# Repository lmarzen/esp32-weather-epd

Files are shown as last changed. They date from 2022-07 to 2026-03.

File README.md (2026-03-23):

# ESP32 E-Paper Weather Display

A low-power weather display using a wifi-enabled ESP32 microcontroller and a 7.5" E-Paper display. Weather data is fetched from the OpenWeatherMap API, and an onboard sensor provides indoor temperature and humidity.

<p float="left">
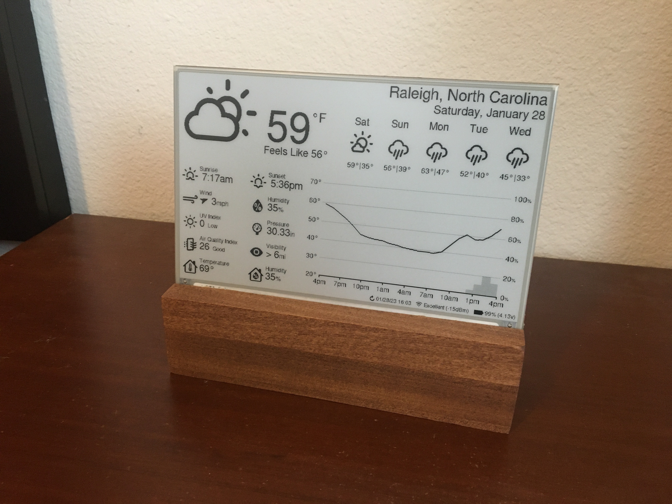
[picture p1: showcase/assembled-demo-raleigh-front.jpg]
  
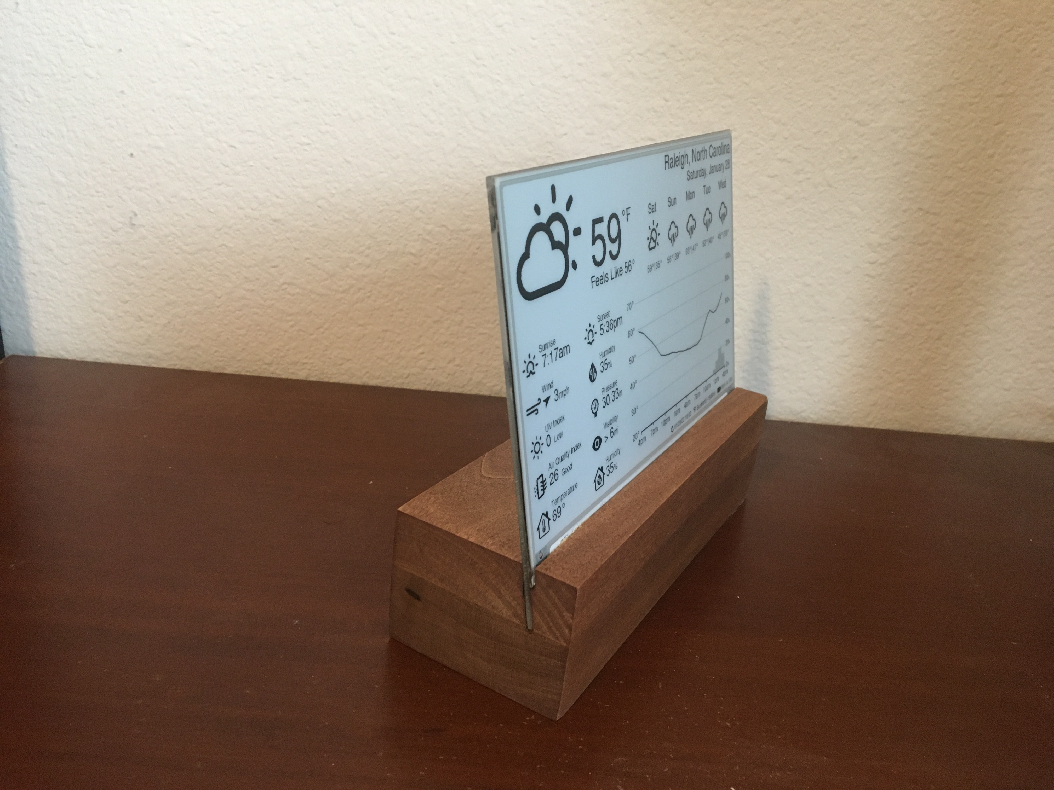
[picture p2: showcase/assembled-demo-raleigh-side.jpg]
  
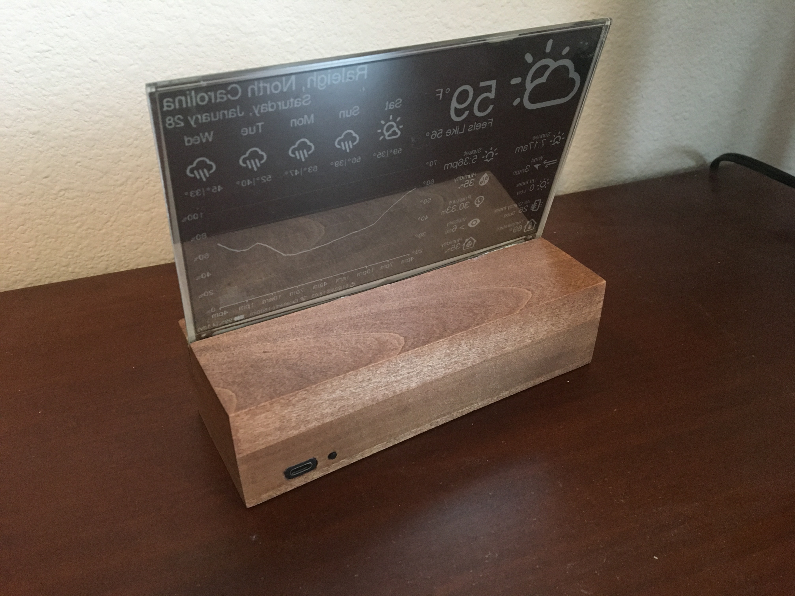
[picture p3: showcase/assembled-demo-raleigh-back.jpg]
  
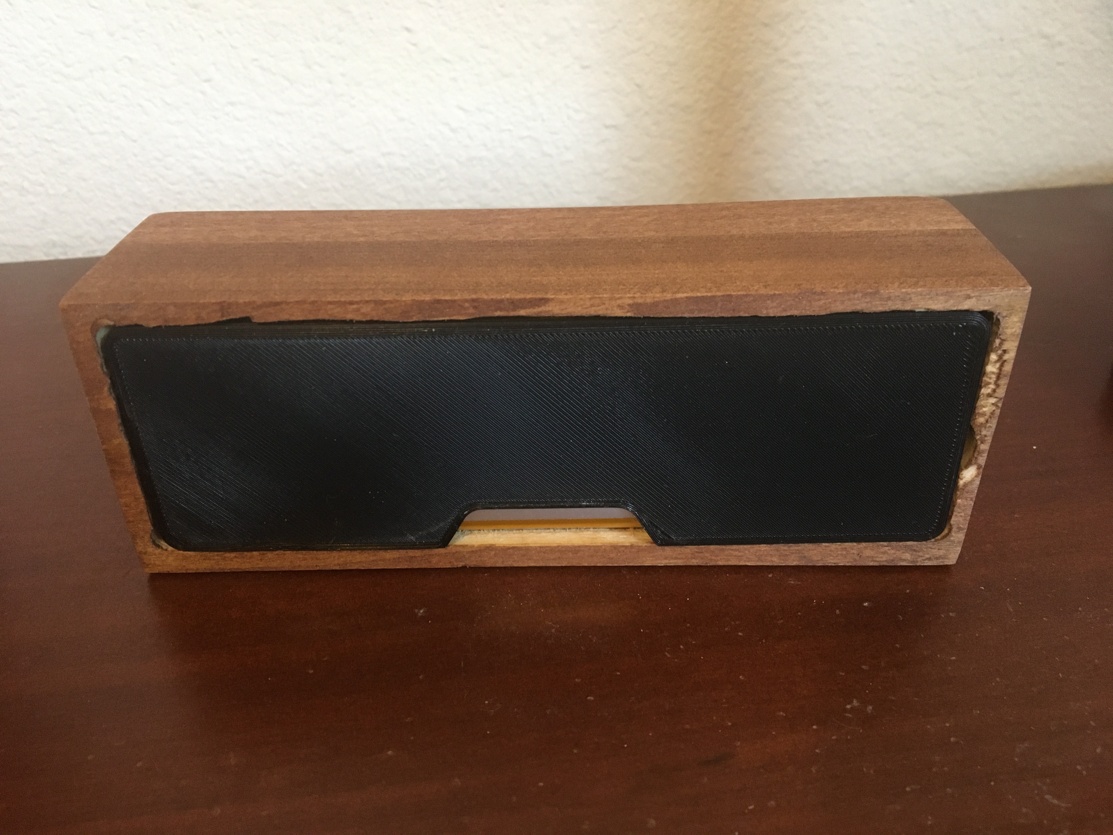
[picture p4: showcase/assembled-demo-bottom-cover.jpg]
  
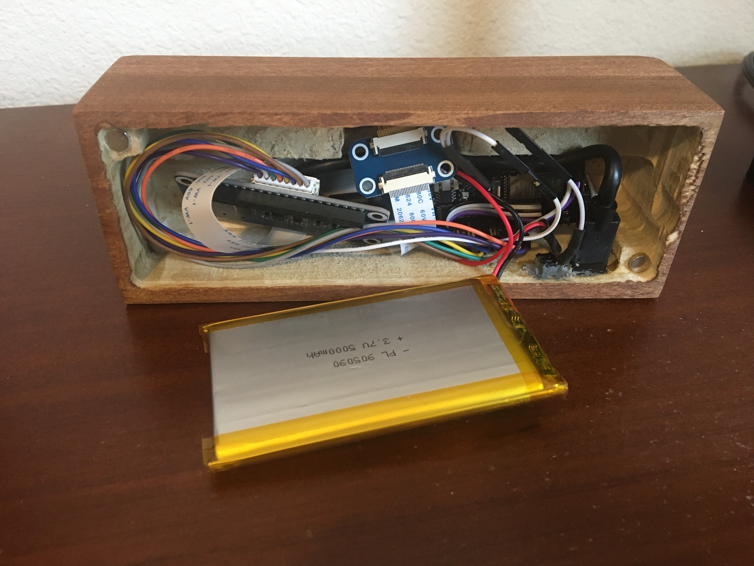
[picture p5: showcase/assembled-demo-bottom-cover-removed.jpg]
  
</p>

## Features

- Ultra-low power consumption: ~14μA in sleep, ~83mA during refresh (~15s).

- Long battery life: 6-12 months on a 5000mAh battery with 30-minute update frequency.

- Customizable display: Supports multiple languages, units, time/date formats, AQI scales, personalization options, and much more.

- Easy recharging: USB-C charging with battery monitoring.

The hourly outlook graph (bottom right) shows a line indicating temperature and shaded bars indicating probability of precipitation (or optionally volume of precipitation).

Here are two (slightly outdated) examples utilizing various configuration options:

<p float="left">
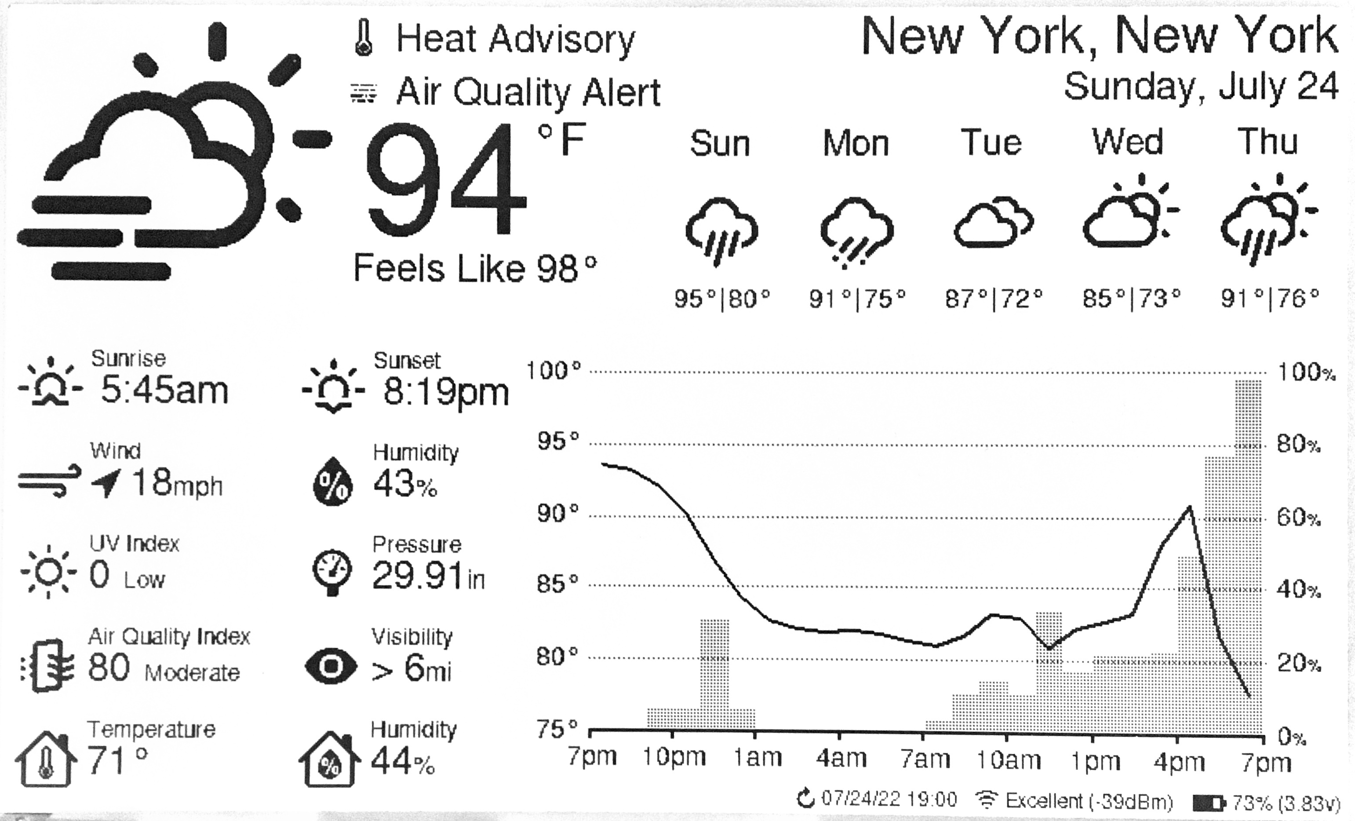
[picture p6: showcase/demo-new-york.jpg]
  
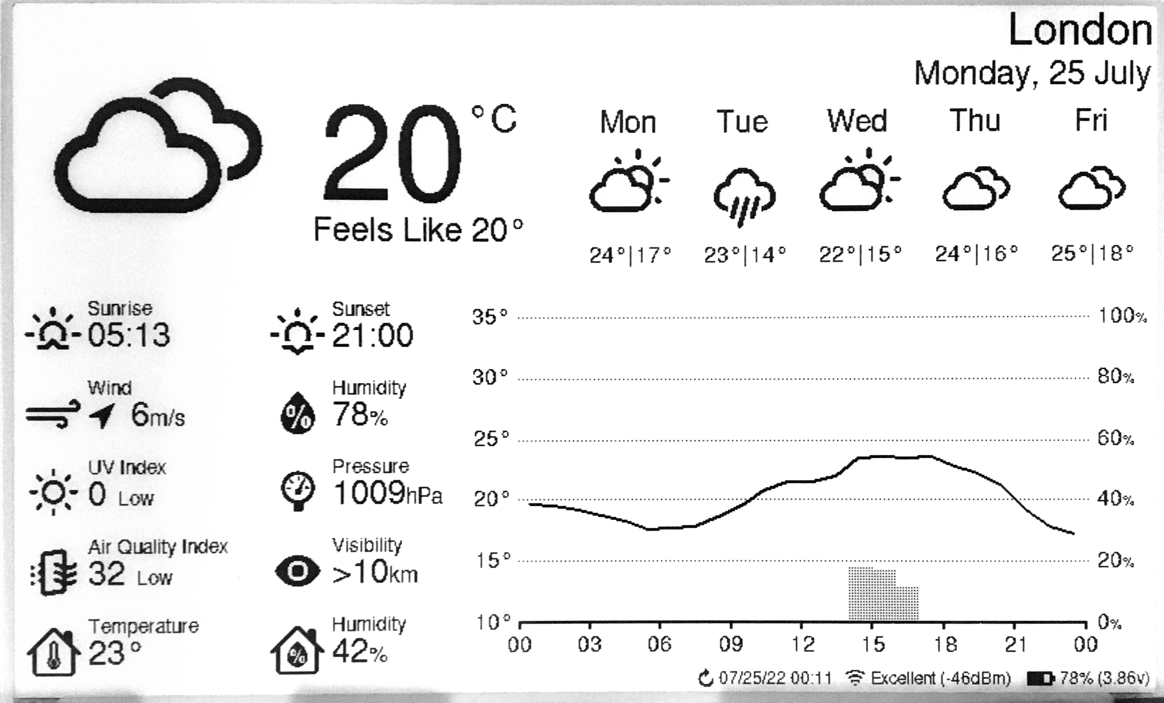
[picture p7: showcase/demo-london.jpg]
  
</p>

## Contents

- [Required Components](#required-components)
  - [Panel Support](#panel-support)
  - [Enclosure Options](#enclosure-options)
  - [Solder-Free Component Selection](#solder-free-component-selection-optional)
- [Setup Guide](#setup-guide)
  - [Wiring](#wiring)
  - [Configuration, Compilation, and Upload](#configuration-compilation-and-upload)
  - [OpenWeatherMap API Key](#openweathermap-api-key)
- [Error Messages and Troubleshooting](#error-messages-and-troubleshooting)
  - [Low Battery](#low-battery)
  - [WiFi Connection](#wifi-connection)
  - [API Error](#api-error)
  - [Time Server Error](#time-server-error)
- [Licensing](#licensing)

## Required Components

  Some links below are affiliate links. Using them helps support the project at no extra cost to you—thanks for your support!

  | Component Type  | Component                                    | Notes                                                     | Link                                                                         |
  |-----------------|----------------------------------------------|-----------------------------------------------------------|------------------------------------------------------------------------------|
  | ESP32           | FireBeetle 2 ESP32-E                         | Features low-power design, USB-C, and battery management. | Available [here](https://www.dfrobot.com/product-2195.html?tracking=PfSxQ8). |
  | E-Paper Display | See [Panel Support](#panel-support).         | See [Panel Support](#panel-support).                      | See [Panel Support](#panel-support).                                         |
  | Adapter Board   | DESPI-C02                                    | Waveshare HATs (rev 2.2/2.3) are not recommended.         | Available [here](https://www.aliexpress.us/item/3256804446769469.html).      |
  | Sensor          | BME280                                       | Temperature, humidity, and pressure. 3.3V/5V compatible.  | Available from multiple vendors.                                             |
  | Battery         | 3.7V LiPo w/ JST-PH2.0 connector             | Any capacity (e.g., 5000mAh for 6+ months runtime)        | Available from multiple vendors.                                             |
  | Enclosure       | See [Enclosure Options](#enclosure-options). | See [Enclosure Options](#enclosure-options).              | See [Enclosure Options](#enclosure-options).                                 |

Other items needed:
- Wires ("Jumper Wires" if looking to minimize/avoid soldering).
- Solder Iron + Solder (unless following [Solder-Free Component Selection](#solder-free-component-selection-optional)).
- Linux, Windows, or MacOS computer (used to configure and install ESP32 firmware).
- Push Button (optional, if you want a reset button mounted on your enslosure, else you can use the on-board reset button).

### Panel Support

  Waveshare and Good Display make equivalent panels. Either variant will work.

  | Panel                                   | Resolution | Colors          | Notes                                                                                                                 |
  |-----------------------------------------|------------|-----------------|-----------------------------------------------------------------------------------------------------------------------|
  | Waveshare 7.5in e-paper (v2)            | 800x480px  | Black/White     | Available [here](https://www.waveshare.com/product/7.5inch-e-paper.htm). (recommended)                                |
  | Good Display 7.5in e-paper (GDEY075T7)  | 800x480px  | Black/White     | Available [here](https://www.aliexpress.com/item/3256802683908868.html).             |
  | Waveshare 7.5in e-Paper (B)             | 800x480px  | Red/Black/White | Available [here](https://www.waveshare.com/product/7.5inch-e-paper-b.htm).                                            |
  | Good Display 7.5in e-paper (GDEY075Z08) | 800x480px  | Red/Black/White | Available [here](https://www.aliexpress.com/item/3256803540460035.html).                                              |
  | Waveshare 7.3in ACeP e-Paper (F)        | 800x480px  | 7-Color         | Available [here](https://www.waveshare.com/product/displays/e-paper/epaper-1/7.3inch-e-paper-f.htm).                  |
  | Good Display 7.3in e-paper (GDEY073D46) | 800x480px  | 7-Color         | Available [here](https://www.aliexpress.com/item/3256805485098421.html).                                              |
  | Waveshare 7.5in e-paper (v1)            | 640x384px  | Black/White     | Limited support. Some information not displayed, see [image](showcase/demo-waveshare75-version1.jpg).                 |
  | Good Display 7.5in e-paper (GDEW075T8)  | 640x384px  | Black/White     | Limited support. Some information not displayed, see [image](showcase/demo-waveshare75-version1.jpg).                 |

  This software has limited support for accent colors. E-paper panels with additional colors tend to have longer refresh times, which will reduce battery life.

### Enclosure Options

You'll want a nice way to show off your project. Here are a few popular choices.

- DIY Wooden
  - I made a small stand by hollowing out a piece of wood from the bottom. On the back, I used a short USB extension cable so that I can charge the battery without needing to remove the components from the stand. I also wired a small reset button to refresh the display manually. Additionally, I 3d printed a cover for the bottom, which is held on by magnets. The E-paper screen is very thin, so I used a thin piece of acrylic to support it.
  - Measurements:
    - depth = 63mm <br>
      height = 49mm <br>
      width = 170.2mm (= width of the screen) <br>
      screen angle = 80deg <br>
      screen is 15mm from the front
- 3D Printable
  - Here is a list of community designs.
  
    | Contributor                                                          | Link                                                                                                      |
    |----------------------------------------------------------------------|-----------------------------------------------------------------------------------------------------------|
    | [Kingfisher](https://www.printables.com/@Kingfisher_32821)           | [Printables](https://www.printables.com/model/1139047-weather-station-e-ink-frame)                        |
    | [Francois Allard](https://www.printables.com/@FrAllard_1585397)      | [Printables](https://www.printables.com/model/791477-weather-station-using-a-esp32)                       |
    | [3D Nate](https://www.printables.com/@3DNate_451157)                 | [Printables](https://www.printables.com/model/661183-e-ink-weather-station-frame)                         |
    | [Sven F.](https://github.com/Spanholz)                               | [Printables](https://www.printables.com/model/657756-case-for-esp32-weather-station)                      |
    | [Layers Studio](https://www.printables.com/@LayersStudio)            | [Printables](https://www.printables.com/model/655768-esp32-e-paper-weather-display-stand)                 |
    | [PJ Veltri](https://www.printables.com/@PJVeltri_1590999)            | [Printables](https://www.printables.com/model/692944-base-and-display-holder-for-esp-32-e-paper-weather)  |
    | [TheMeanCanEHdian](https://www.printables.com/@TheMeanCanEH_1207348) | [Printables](https://www.printables.com/model/841458-weather-display-enclosure)                           |
    | [MPHarms](https://www.thingiverse.com/mpharms/designs)               | [Thingiverse](https://www.thingiverse.com/thing:6666148)                                                  |
    | [Plaste-Metz](https://www.printables.com/@PlasteMetz_576567)         | [Printables](https://www.printables.com/model/1160924-weather-station-case)                               |
    | [kenwch92](https://github.com/kenwch92)                              | [Printables](https://www.printables.com/model/1505838-over-engineered-display-stand-for-esp32-e-paper-we) |
    | [Eckerput](https://github.com/Eckerput)                              | [Thingiverse](https://www.thingiverse.com/thing:7112836)                                                  |
    | [Thomax ](https://www.printables.com/@Thomax_386720)                 | [Printables](https://www.printables.com/model/1363448-esp32-e-paper-weather-display) |

  - If you want to share your own 3D printable designs, your contributions are highly encouraged and welcome!
- Picture Frame

### Solder-Free Component Selection (Optional)

This project can be completed without any soldering, if you choose your component selection carefully.
- Buy "Jumper Wires" to connect your components.
- Buy the [FireBeetle 2 ESP32-E w/ Headers](https://www.dfrobot.com/product-2231.html?tracking=PfSxQ8).
- Buy a BME280 with headers soldered from the factory.
- Buy a reset switch that is compatible with jumper wires.

## Setup Guide

### Wiring

The battery can be charged by plugging the FireBeetle ESP32 into the wall via the USB-C connector while the battery is plugged into the ESP32's JST connector.

  > **Warning**
  > The polarity of JST-PH2.0 connectors is not standardized! You may need to swap the order of the wires in the connector.

NOTE: Waveshare now ships revision 2.3 of their e-paper HAT (no longer rev 2.2 ). Rev 2.3 has an additional `PWR` pin (not depicted in the wiring diagrams below); connect this pin to 3.3V.

IMPORTANT: The DESPI-C02 adapter has one physical switch that MUST be set correctly for the display to work.

- RESE: Set switch to position 0.47.

IMPORTANT: The Waveshare E-Paper Driver HAT has two physical switches that MUST be set correctly for the display to work.

- Display Config: Set switch to position B.

- Interface Config: Set switch to position 0.

Cut the low power pad for even longer battery life.

- From <https://wiki.dfrobot.com/FireBeetle_Board_ESP32_E_SKU_DFR0654>

  > Low Power Pad: This pad is specially designed for low power consumption. It is connected by default. You can cut off the thin wire in the middle with a knife to disconnect it. After disconnection, the static power consumption can be reduced by 500 μA. The power consumption can be reduced to 13 μA after controlling the maincontroller enter the sleep mode through the program. Note: when the pad is disconnected, you can only drive RGB LED light via the USB Power supply.

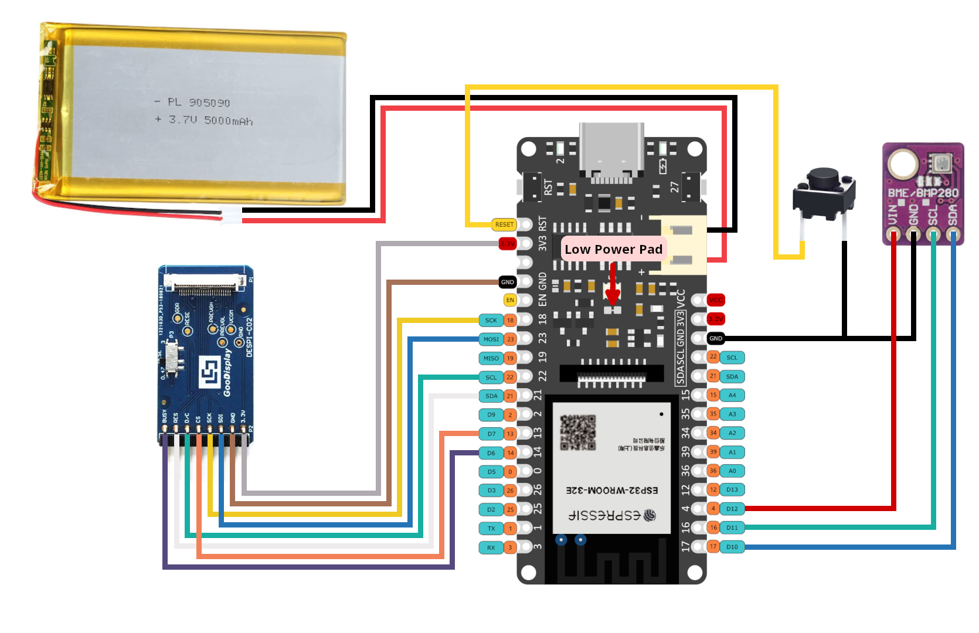
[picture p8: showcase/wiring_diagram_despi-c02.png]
Wiring diagram with DESPI-C02 driver board.


### Configuration, Compilation, and Upload

PlatformIO for VSCode is used for managing dependencies, code compilation, and uploading to ESP32.

1. Clone this repository or download and extract the .zip.

2. Install VSCode.

3. Follow these instructions to install the PlatformIO extension for VSCode: <https://platformio.org/install/ide?install=vscode>

4. Open the project in VSCode.

   a. File > Open Folder...

   b. Navigate to this project and select the folder called "platformio".

5. Configure Options.

   - Most configuration options are located in [config.cpp](platformio/src/config.cpp), with a few  in [config.h](platformio/include/config.h).

   - Important settings to configure in config.cpp:

     - WiFi credentials (ssid, password).

     - Open Weather Map API key (it's free, see next section for important notes about obtaining an API key).

     - Latitude and longitude.

     - Time and date formats.

     - Sleep duration.

   - Important settings to configure in config.h:

     - Units (Metric or Imperial).

   - Comments explain each option in detail.

6. Build and Upload Code.

   a. Connect ESP32 to your computer via USB.

   b. Click the upload arrow along the bottom of the VSCode window. (Should say "PlatformIO: Upload" if you hover over it.)

      - PlatformIO will automatically download the required third-party libraries, compile, and upload the code. :)

      - You will only see this if you have the PlatformIO extension installed.

      - If using a FireBeetle 2 ESP32-E and you receive the error `Wrong boot mode detected (0x13)! The chip needs to be in download mode.` unplug the power from the board, connect GPIO0 ([labeled 0/D5](https://wiki.dfrobot.com/FireBeetle_Board_ESP32_E_SKU_DFR0654#target_5)) to GND, and power it back up to put the board in download mode.

      - If you are getting other errors during the upload process, you may need to install drivers to allow you to upload code to the ESP32.

### OpenWeatherMap API Key

Sign up here to get an API key; it's free. <https://openweathermap.org/api>

This project will make calls to 2 different APIs ("One Call" and "Air Pollution").

- The One Call API 3.0 is only included in the "One Call by Call" subscription. This separate subscription includes 1,000 calls/day for free and allows you to pay only for the number of API calls made to this product.

Here's how to subscribe and avoid any credit card changes:
   - Go to <https://home.openweathermap.org/subscriptions/billing_info/onecall_30/base?key=base&service=onecall_30>
   - Follow the instructions to complete the subscription.
   - Go to <https://home.openweathermap.org/subscriptions> and set the "Calls per day (no more than)" to 1,000. This ensures you will never overrun the free calls.

## Error Messages and Troubleshooting

### Low Battery
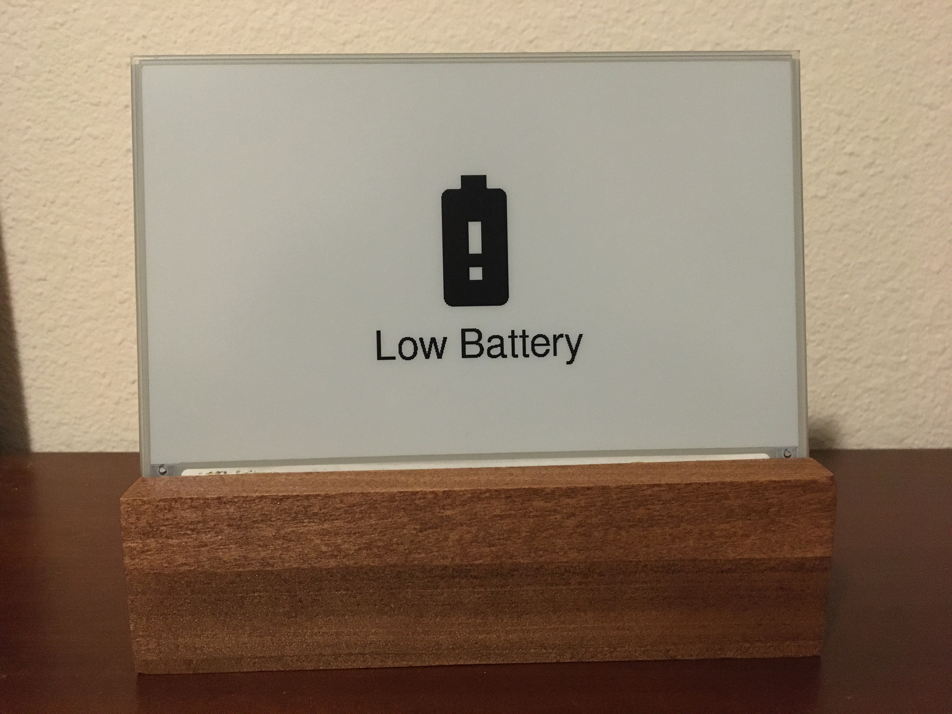
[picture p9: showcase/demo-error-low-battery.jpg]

This error screen appears once the battery voltage has fallen below LOW_BATTERY_VOLTAGE (default = 3.20v). The display will not refresh again until it detects battery voltage above LOW_BATTERY_VOLTAGE. When battery voltage is between LOW_BATTERY_VOLTAGE and VERY_LOW_BATTERY_VOLTAGE (default = 3.10v) the esp32 will deep-sleep for periods of LOW_BATTERY_SLEEP_INTERVAL (default = 30min) before checking battery voltage again. If the battery voltage falls between LOW_BATTERY_SLEEP_INTERVAL and CRIT_LOW_BATTERY_VOLTAGE (default = 3.00v), then the display will deep-sleep for periods VERY_LOW_BATTERY_SLEEP_INTERVAL (default = 120min). If battery voltage falls below CRIT_LOW_BATTERY_VOLTAGE, then the esp32 will enter hibernate mode and will require a manual push of the reset (RST) button to begin updating again.

<br clear="left"/>

### WiFi Connection
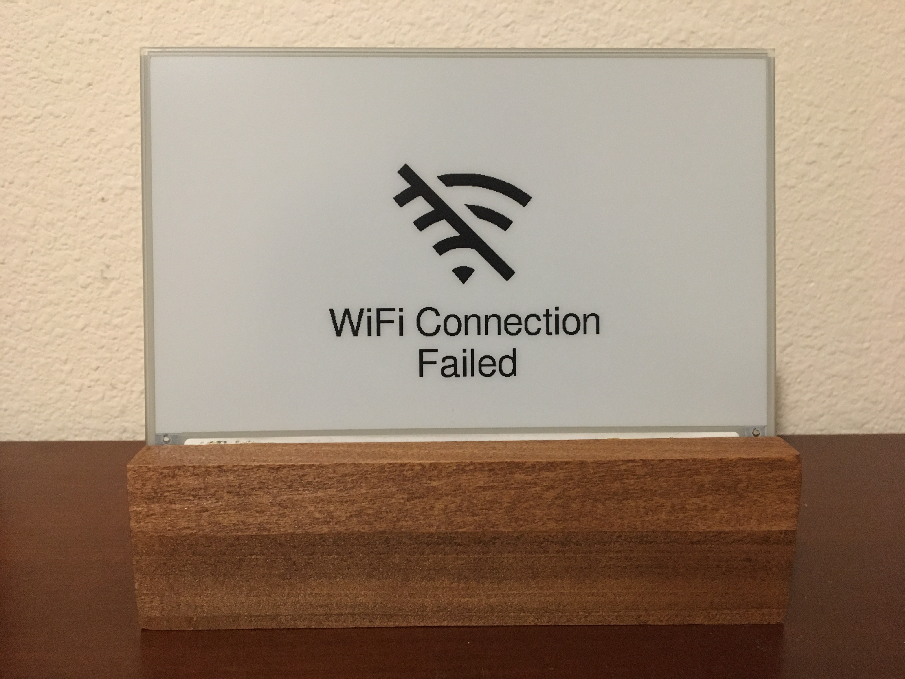
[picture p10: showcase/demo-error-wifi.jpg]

This error screen appears when the ESP32 fails to connect to WiFi. If the message reads "WiFi Connection Failed" this might indicate an incorrect password. If the message reads "SSID Not Available" this might indicate that you mistyped the SSID or that the esp32 is out of the range of the access point. The esp32 will retry once every SLEEP_DURATION (default = 30min).

<br clear="left"/>

### API Error
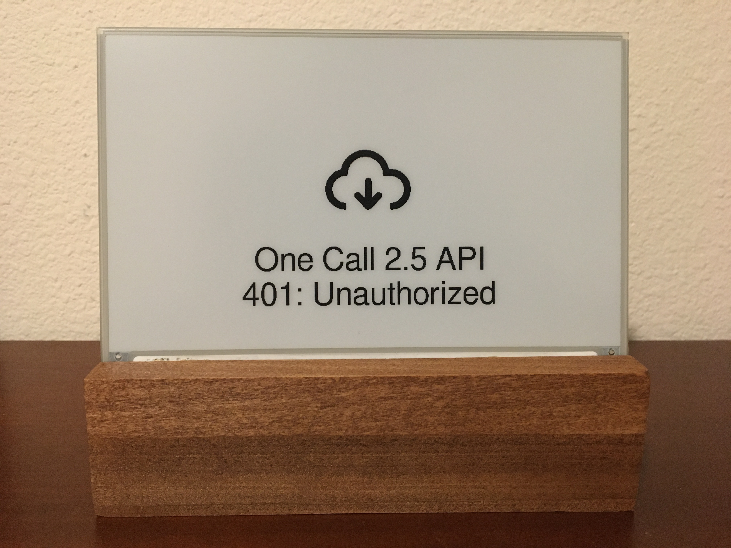
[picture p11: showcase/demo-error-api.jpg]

This error screen appears if an error (client or server) occurs when making an API request to OpenWeatherMap. The second line will give the error code followed by a descriptor phrase. Positive error codes correspond to HTTP response status codes, while error codes <= 0 indicate a client(esp32) error. The esp32 will retry once every SLEEP_DURATION (default = 30min).
<br/><br/>
In the example shown to the left, "401: Unauthorized" may be the result of an incorrect API key or that you are attempting to use the One Call v3 API without the proper account setup.

<br clear="left"/>

### Time Server Error
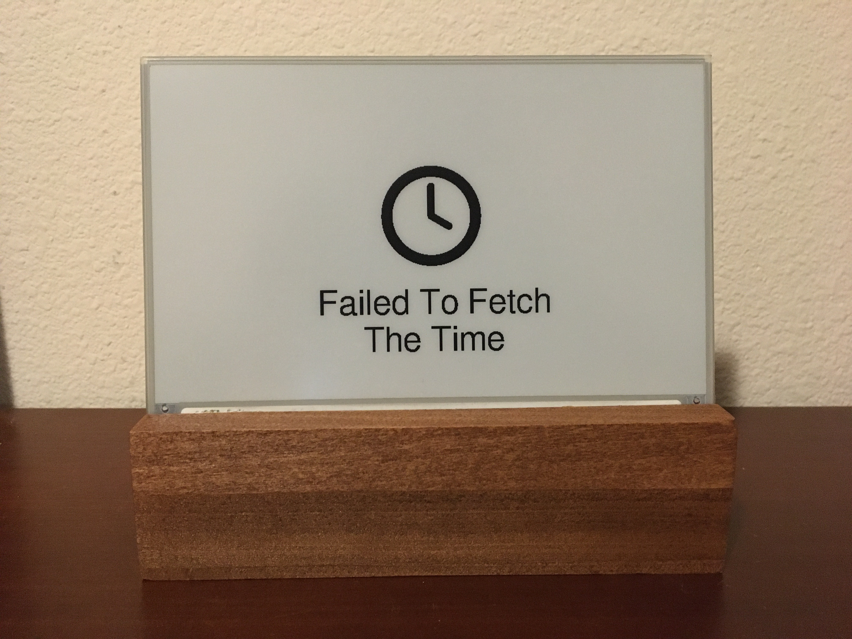
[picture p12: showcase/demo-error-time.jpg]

This error screen appears when the esp32 fails to fetch the time from NTP_SERVER_1/NTP_SERVER_2. This error sometimes occurs immediately after uploading to the esp32; in this case, just hit the reset button or wait for SLEEP_DURATION (default = 30min) and the esp32 to automatically retry. If the error persists, try selecting closer/lower latency time servers or increasing NTP_TIMEOUT.

<br clear="left"/>

## Licensing

esp32-weather-epd is licensed under the [GNU General Public License v3.0](LICENSE) with tools, fonts, and icons whose licenses are as follows:

| Name | License | Description |
|---|---|---|
| [Adafruit-GFX-Library: fontconvert](https://github.com/adafruit/Adafruit-GFX-Library/tree/master/fontconvert) | [BSD License](fonts/fontconvert/license.txt) | CLI tool for preprocessing fonts to be used with the Adafruit_GFX Arduino library. |
| [pollutant-concentration-to-aqi](https://github.com/lmarzen/pollutant-concentration-to-aqi) | [GNU Lesser General Public License v2.1](platformio/lib/pollutant-concentration-to-aqi/LICENSE) | C library that converts pollutant concentrations to Air Quality Index(AQI). |
| [GNU FreeFont](https://www.gnu.org/software/freefont/) | [GNU General Public License v3.0](https://www.gnu.org/software/freefont/license.html) | Font Family |
| [Lato](https://fonts.google.com/specimen/Lato) | [SIL OFL v1.1](http://scripts.sil.org/OFL) | Font Family |
| [Montserrat](https://fonts.google.com/specimen/Montserrat) | [SIL OFL v1.1](http://scripts.sil.org/OFL) | Font Family |
| [Open Sans](https://fonts.google.com/specimen/Open+Sans) | [SIL OFL v1.1](http://scripts.sil.org/OFL) | Font Family |
| [Poppins](https://fonts.google.com/specimen/Poppins) | [SIL OFL v1.1](http://scripts.sil.org/OFL) | Font Family |
| [Quicksand](https://fonts.google.com/specimen/Quicksand) | [SIL OFL v1.1](http://scripts.sil.org/OFL) | Font Family |
| [Raleway](https://fonts.google.com/specimen/Raleway) | [SIL OFL v1.1](http://scripts.sil.org/OFL) | Font Family |
| [Roboto](https://fonts.google.com/specimen/Roboto) | [Apache License v2.0](https://www.apache.org/licenses/LICENSE-2.0) | Font Family |
| [Roboto Mono](https://fonts.google.com/specimen/Roboto+Mono) | [Apache License v2.0](https://www.apache.org/licenses/LICENSE-2.0) | Font Family |
| [Roboto Slab](https://fonts.google.com/specimen/Roboto+Slab) | [Apache License v2.0](https://www.apache.org/licenses/LICENSE-2.0) | Font Family |
| [Ubuntu font](https://design.ubuntu.com/font) | [Ubuntu Font Licence v1.0](https://ubuntu.com/legal/font-licence) | Font Family |
| [Weather Themed Icons](https://github.com/erikflowers/weather-icons) | [SIL OFL v1.1](http://scripts.sil.org/OFL) | (wi-**.svg) Weather icon family by Lukas Bischoff/Erik Flowers. |
| [Google Icons](https://fonts.google.com/icons) | [Apache License v2.0](https://www.apache.org/licenses/LICENSE-2.0) | (battery**.svg, visibility_icon.svg) Battery and visibility icons from Google Icons. |
| [Biological Hazard Symbol](https://svgsilh.com/image/37775.html) | [CC0 v1.0](https://en.wikipedia.org/wiki/Public_domain) | (biological_hazard_symbol.svg) Biohazard icon. |
| [House Icon](https://seekicon.com/free-icon/house_16) | [MIT License](http://opensource.org/licenses/mit-license.html) | (house.svg) House icon. |
| [Indoor Temerature/Humidity Icons](icons/svg) | [SIL OFL v1.1](http://scripts.sil.org/OFL) | (house_**.svg) Indoor temerature/humidity icons. |
| [Ionizing Radiation Symbol](https://svgsilh.com/image/309911.html) | [CC0 v1.0](https://creativecommons.org/publicdomain/zero/1.0/) | (ionizing_radiation_symbol.svg) Ionizing radiation icons. |
| [Phosphor Icons](https://github.com/phosphor-icons/homepage) | [MIT License](http://opensource.org/licenses/mit-license.html) | (wifi**.svg, warning_icon.svg, error_icon.svg) WiFi, Warning, and Error icons from Phosphor Icons. |
| [Wind Direction Icon](https://www.onlinewebfonts.com/icon/251550) | [CC BY v3.0](http://creativecommons.org/licenses/by/3.0) | (meteorological_wind_direction_**deg.svg) Meteorological wind direction icon from Online Web Fonts. |

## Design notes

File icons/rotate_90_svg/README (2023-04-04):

Simple script to rotate svg files in 90 deg increments.

Usage:
bash generate_rotated_90.sh <icon.svg>

Example:
bash generate_rotated_90.sh battery_0_bar.svg

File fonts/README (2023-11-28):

Instructions for running ttf_to_adafruit_gfx.sh:

Dependencies:
  fonttools
    fonttools must be installed
    pyftsubset is part of fonttools, a python based command line tool for
    manipulating fonts. pyftsubset will be used to generate 2 subsets of the
    desired font.
  Adafruit fontconvert
    Adafruit provides a tool as part of their Adafruit GFX Library that converts
    font files to c-style arrays that can be used by the before-mentioned
    library. The necessary components have been included as part of this
    repository AND REMAIN LICENSED UNDER ITS ORIGINAL LICENSE AGREEMENT. A COPY
    OF THIS LICENSE IS PROVIDED ALONGSIDE THE SOURCE IN THE 'fontconvert'
    SUB-DIRECTORY OF THIS FOLDER.
    https://github.com/adafruit/Adafruit-GFX-Library/tree/master/fontconvert
  freetype2
    dependency for fontconvert.

How do I generate different sizes of fonts?
  In ttf_to_adafruit_gfx.sh there is an array called SIZES which specifies what
  size fonts should be generated.

How do I generate and add files for a new font?
  Add the .ttf or .otf file to the ./ttf directory then run the script.
  The script will generate a new subdirectory, ./fonts.
  Manually move the newly generated font fonts folder to
  platformio/lib/esp32-weather-epd-assets/fonts.

To run this script execute the following command:
  bash ttf_to_adafruit_gfx.sh

What does this script do?
  This script converts ttf or otf (font) files to c-style arrays to be used by
  the Adafruit GFX Library.

  2 font subsets will be generated:
    1. Extended ASCII (ISO-8859-1)
    2. Numbers (0-9), decimal point (.), dash (-), and the degree symbol (°)

  This is done to conserve EEPROM space.
  (only need 0..9/./-/° for the large primary temperature display)

The fonts used for this project could be swapped out relatively easily if
desired.

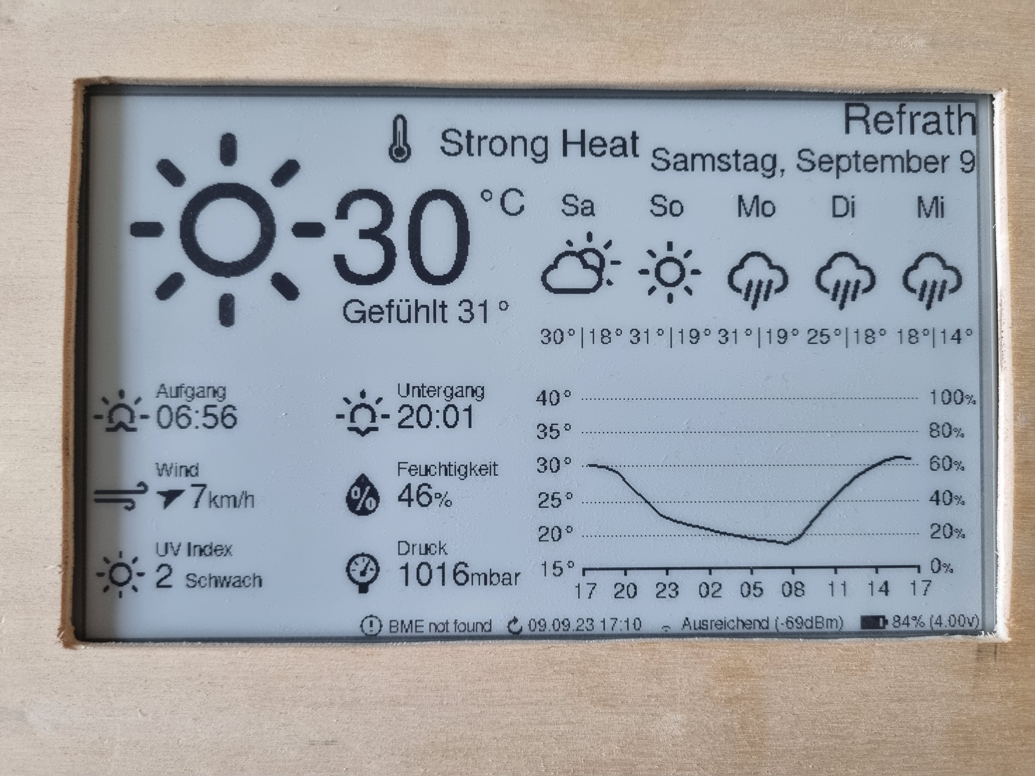
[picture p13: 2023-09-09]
showcase/demo-waveshare75-version1.jpg

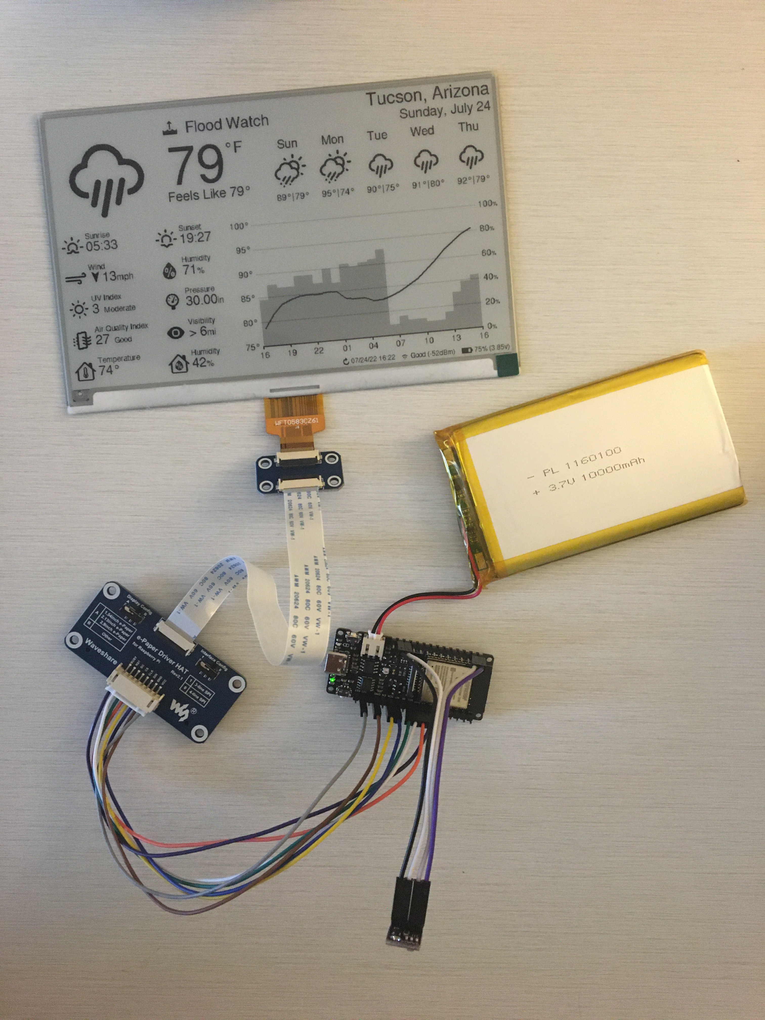
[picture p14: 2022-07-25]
showcase/demo-tucson.jpg

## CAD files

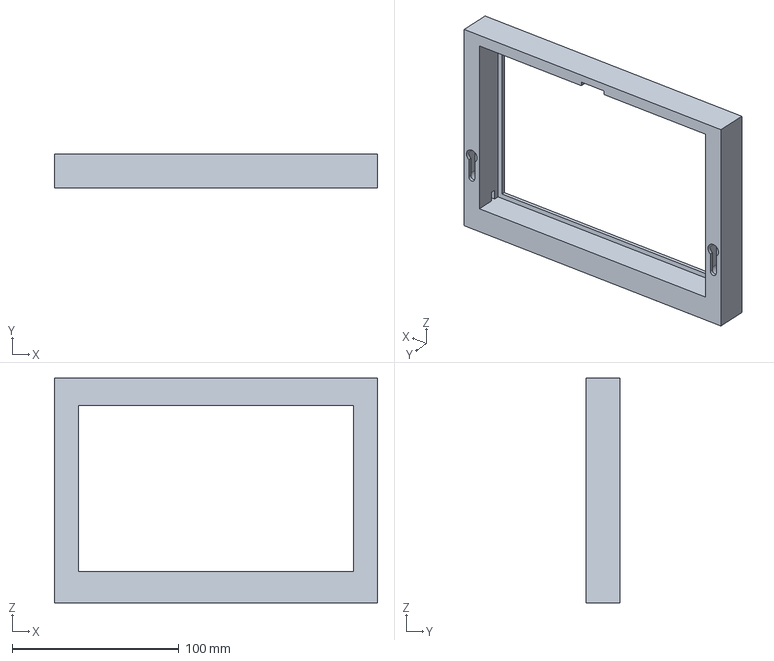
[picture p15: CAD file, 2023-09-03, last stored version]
3d_models/frame_variant_1/frame.stp
194.0 x 20.2 x 135.0 mm

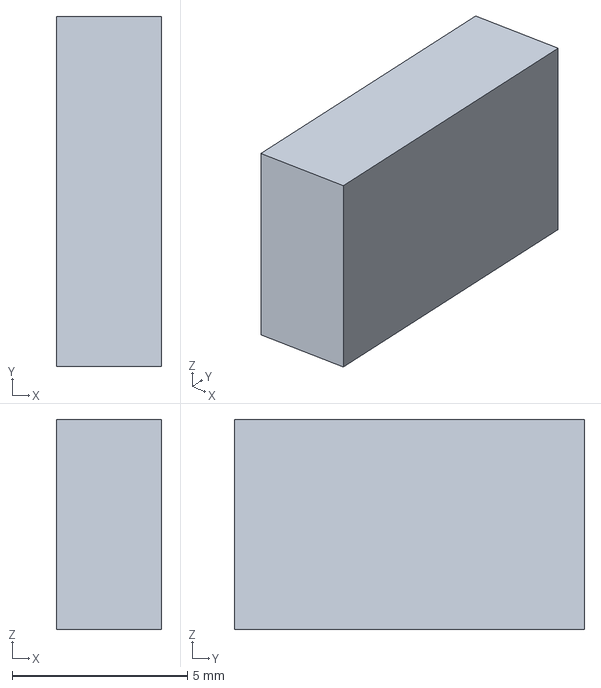
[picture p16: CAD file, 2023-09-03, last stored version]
3d_models/frame_variant_1/retainers.stp
3.00 x 10.0 x 6.00 mm

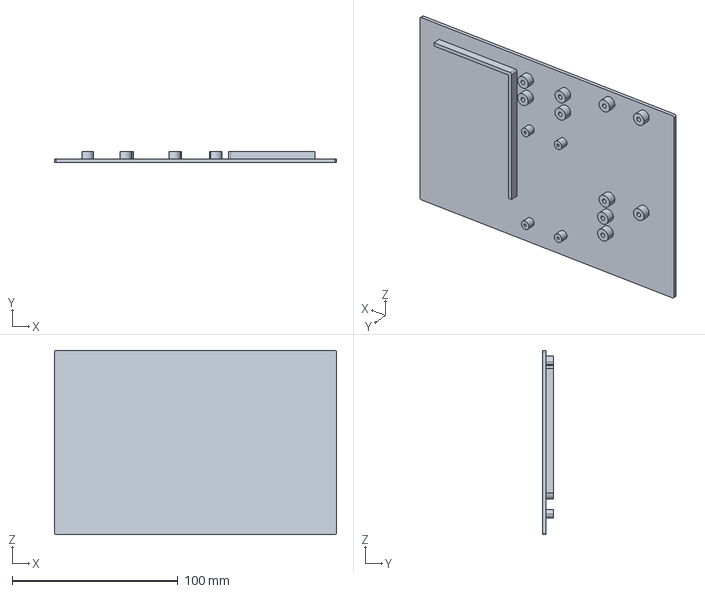
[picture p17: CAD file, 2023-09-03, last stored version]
3d_models/frame_variant_1/mount_plate.stp
170.0 x 6.50 x 111.0 mm

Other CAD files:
3d_models/frame_variant_1/frame.stl
3d_models/frame_variant_1/mount_plate.stl
3d_models/frame_variant_1/retainers.stl

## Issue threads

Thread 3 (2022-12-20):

firebeetle v2 esp32-e upload issue

Dozentz, 2022-12-20:
Will work from usb? I have a constantly blinking red battery light and a white screen

lmarzen, 2022-12-20:
Yes it will work over usb.If pressing the reset button doesn't cause the display to do anything then it may be wired incorrectly?

Dozentz, 2022-12-20:
Connected as picture
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

lmarzen, 2022-12-20:
The switches on the e-paper hat. "Interface Config: Set switch to position 1."

lmarzen, 2022-12-20:
You could also try disconnecting it from usb power and then reconnecting it. Sometimes the esp32s can be finicky after you upload your code.

Dozentz, 2022-12-20:
I turned off the power and turned it on again, set the flag to 1. Tell me what else can be done?

lmarzen, 2022-12-20:
Are you sure the code was successfully uploaded to the esp32?

lmarzen, 2022-12-20:
I'm running out of ideas; maybe a try to disconnect and reconnect the connectors?

Dozentz, 2022-12-21:
upload complete ?
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

lmarzen, 2022-12-21:
yup, that looks good:/

lmarzen, 2022-12-21:
open the serial monitor while the esp32 is connected via usb. It will print debug debug messages that indicate what it is doing.

Dozentz, 2022-12-21:
Tell me how to do it?

lmarzen, 2022-12-21:
in vscode at the bottom(near upload and build buttons) there should be a button to open the serial monitor. Hover over the buttons to find it. Once you find and click it, press the reset button on the esp32, then the esp32 should print out some debug messages that i put in the code to indicate what it is doing. If the esp32 is hanging somewhere this should give me enough information to figure out what might be causing it.

Dozentz, 2022-12-21:
debug
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

lmarzen, 2022-12-21:
Oh weird, looks to be having a boot error before it is executing any of my code. I can look into this, but I am traveling for the holidays and wont be able to try to recreate the issue until mid next month.

Dozentz, 2023-01-16:
Good afternoon. Were you able to fix the error?

lmarzen, 2023-01-16:
I forgot about this over holiday, I have some time today to work on it. I will keep you updated.

lmarzen, 2023-01-16:
I am able to recreate the issue you were describing simply by uploading my existing known good project. Some configuration thing must have changed. hmmmmm

lmarzen, 2023-01-16:
I found another group of people with the same issue. https://github.com/esphome/issues/issues/3921

lmarzen, 2023-01-16:
So I guess the issue is that the firebeetle v2 that I used for this project only has 4MB of flash, while other versions of the esp32 have more flash. I have no idea why it was working before if this is the issue. Sounds like some upload tool got smarter and that the firebeetle v2 might also not have proper support. I have no idea what has happened, I guess I will change my controller out for the older firebeetle that has 16MB of flash and micro usb.

Dozentz, 2023-01-16:
My controller version is type С. How can I find out how much flash memory is in my version?

lmarzen, 2023-01-16:
https://www.dfrobot.com/product-2195.html vs https://www.dfrobot.com/product-1590.html

lmarzen, 2023-01-16:
The usb C version is only 4MB. Somehow this never caused an issue until now, even though the compiled code is like 11MB.

Dozentz, 2023-01-16:
I understand the problem is now with the compiler

lmarzen, 2023-01-16:
No my understanding is that this board is properly supported in platformio and that when I originally created this project for some reason I was able to upload a bigger binary to the controller without it freaking out, but now there is some extra check or maybe even just a change in environment that is causing this issues. I have no idea why this worked in the first place with a 4MB flash. Clearly 11MB > 4MB. I must have over looked that the newer usb c firebeetle had less flash than its predecessor. So the solution is that you must buy the micro usb firebeetle because that has 16mb of flash. I am testing it now because I have the hardware on hand.

lmarzen, 2023-01-16:
Okay, I have dug more into it. It seems to be a support issue with platformio. Maybe not flash size issue?

Dozentz, 2023-01-16:
Need to ask on the forum https://community.platformio.org.

lmarzen, 2023-01-16:
Alright, forget my earlier explanation. I think I got it now. So the Firebeetle v2 esp32-e is not official supported but it worked earlier last year. So the solution is to use an older version of expressif32, So in platform.ini try change `platform = espressif32` to `platform = espressif32@5.0.0`

lmarzen, 2023-01-16:
https://github.com/platformio/platform-espressif32/issues/644

lmarzen, 2023-01-17:
Alright. Fingers crossed, the issue should be fixed now. Let me know how it goes.

Dozentz, 2023-01-17:
Ok

Dozentz, 2023-01-18:
Everything worked. Great job. Tell me how to make a weather icon shadow with curves and a battery with 4 compartments. Thanks to)
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

lmarzen, 2023-01-18:
I created a new issue with instructions for changing icons. https://github.com/lmarzen/esp32-weather-epd/issues/4

Closed 2023-01-18.

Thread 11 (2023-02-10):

One Call deserializeJson() failed: IncompleteInput

nglessner, 2023-02-10:
I am able to connect to wifi, pull down the time from the NTP server, but then I get an error "One Call deserializeJson() failed: IncompleteInput"

This repeats 3x before continuing on.  I can confirm that in [Open Weather API Subscriptions](https://home.openweathermap.org/subscriptions) that I see the call attempts increase.  I am following this project verbatim using a DFRobot Firebeetle 2 (ESP32-E) and a BME-280.

lmarzen, 2023-02-10:
Hi nglessner, I will look into this and see if I can reproduce it.  When you have time, could you please provide **sanitized** copies of your config.cpp and config.h? (remove wifi ssid/password, api key) You may also want to obfuscate your lat long. If you decide to obfuscate your location, please make sure that you still get the same error for the new lat/long.

Thanks, Luke.

lmarzen, 2023-02-10:
https://arduinojson.org/v6/api/misc/deserializationerror/#deserializationerrorincompleteinput
> The end of the input is missing. Possible reasons:
>    - a buffer was too small to contains the input
>    - a timeout occurred when reading from a stream

Hopefully increasing one of these 2 things can fix resolve this issue.

nglessner, 2023-02-10:
I'm guessing it'll be the second one. I was looking at the first possible cause, but I'm seeing my free heap go down by just over 32k which is what I'd expect.

Heap: 148955
Heap: 116175
One Call deserializeJson() failed: IncompleteInput
Heap: 147011
Heap: 114231
One Call deserializeJson() failed: IncompleteInput
Heap: 148731
Heap: 115951
One Call deserializeJson() failed: IncompleteInput

nglessner, 2023-02-10:
Here's my config:

#include <vector>
#include <Arduino.h>
#include "config.h"

// PINS
// ADC pin used to measure battery voltage
const uint8_t PIN_BAT_ADC  = A2;
// Pins for Waveshare e-paper Driver Board
const uint8_t PIN_EPD_BUSY = 13;
const uint8_t PIN_EPD_CS   =  2;
const uint8_t PIN_EPD_RST  = 21;
const uint8_t PIN_EPD_DC   = 22;
const uint8_t PIN_EPD_SCK  = 18;
const uint8_t PIN_EPD_MISO = 19; // 19 Master-In Slave-Out not used, as no data from display
const uint8_t PIN_EPD_MOSI = 23;
// I2C Pins used for BME280
const uint8_t PIN_BME_SDA = 17;
const uint8_t PIN_BME_SCL = 16;
const uint8_t BME_ADDRESS = 0x76; // if sensor does not work, try 0x77

// WIFI CREDENTIALS
const char *WIFI_SSID     = "XXXXX";
const char *WIFI_PASSWORD = "XXXXX";

// OPENWEATHERMAP API
// OpenWeatherMap API key, https://openweathermap.org/
const String OWM_APIKEY   = "XXXXX";
const String OWM_ENDPOINT = "api.openweathermap.org";
// OpenWeatherMap One Call 2.5 API is deprecated for all new free users
// (accounts created after Summer 2022).
//
// Please note, that One Call API 3.0 is included in the "One Call by Call"
// subscription only. This separate subscription includes 1,000 calls/day for
// free and allows you to pay only for the number of API calls made to this
// product.
//
// Here’s how to subscribe and avoid any credit card changes:
// - Go to https://home.openweathermap.org/subscriptions/billing_info/onecall_30/base?key=base&service=onecall_30
// - Follow the instructions to complete the subscription.
// - Go to https://home.openweathermap.org/subscriptions and set the "Calls per
//   day (no more than)" to 1,000. This ensures you will never overrun the free
//   calls.
const String OWM_ONECALL_VERSION = "3.0";

// LOCATION
// Set your latitude and longitude.
// (used to get weather data as part of API requests to OpenWeatherMap)
const String LAT = "39.6910";
const String LON = "-89.7105";
// City name that will be shown in the top-right corner of the display.
const String CITY_STRING = "City, State";

// TIME
// For list of time zones see
// https://github.com/nayarsystems/posix_tz_db/blob/master/zones.csv
const char *TIMEZONE = "CST6CDT,M3.2.0,M11.1.0";
// Time format used when displaying sunrise/set times. (Max 11 characters)
// For more information about formatting see
// https://man7.org/linux/man-pages/man3/strftime.3.html
// const char *TIME_FORMAT = "%l:%M%P"; // 12-hour ex: 1:23am  11:00pm
const char *TIME_FORMAT = "%l:%M%P";   // 24-hour ex: 01:23   23:00
// Time format used when displaying axis labels. (Max 11 characters)
// For more information about formatting see
// https://man7.org/linux/man-pages/man3/strftime.3.html
// const char *HOUR_FORMAT = "%l%P"; // 12-hour ex: 1am  11pm
const char *HOUR_FORMAT = "%l%P";      // 24-hour ex: 01   23
// Date format used when displaying date in top-right corner. For more
// For more information about formatting see
// https://man7.org/linux/man-pages/man3/strftime.3.html
const char *DATE_FORMAT = "%A, %B %e"; // Saturday, January 1
// Date/Time format used when displaying the last refresh time along the bottom
// of the screen
// For more information about formatting see
// https://man7.org/linux/man-pages/man3/strftime.3.html
const char *REFRESH_TIME_FORMAT = "%x %H:%M";
// NTP_SERVER_1 is the primary time server, while NTP_SERVER_2 is a fallback.
// In most cases it's best to use pool.ntp.org to find an NTP server
// The system will try finding the closest available servers for you.
const char *NTP_SERVER_1 = "us.pool.ntp.org";
const char *NTP_SERVER_2 = "time.nist.gov";
// Sleep duration in minutes. (aka how often esp32 will wake for an update)
// Aligned to the nearest minute boundary, so if 30 will always update at 00 or
// 30 past the hour.
const long SLEEP_DURATION = 10;
// If BED_TIME == WAKE_TIME, then this battery saving feature will be disabled.
const int BED_TIME  = 00; // Last update at 00:00 (midnight) until WAKE_TIME.
const int WAKE_TIME = 05; // Hour of first update after BED_TIME, 06:00.

// HOURLY OUTLOOK GRAPH
// Number of hours to display on the outlook graph.
// Value must be between 8-48 (inclusively).
const int HOURLY_GRAPH_MAX = 24;

// BATTERY
// To protect the battery upon LOW_BATTERY_VOLTAGE, the display will cease to
// update until battery is charged again. The ESP32 will deep-sleep (consuming
// < 11μA), waking briefly check the voltage at the corresponding interval (in
// minutes). Once the battery voltage has fallen to CRIT_LOW_BATTERY_VOLTAGE,
// the esp32 will hibernate and a manual press of the reset (RST) button to
// begin operating again.
const float LOW_BATTERY_VOLTAGE      = 3.20; // (volts)
const float VERY_LOW_BATTERY_VOLTAGE = 3.10; // (volts)
const float CRIT_LOW_BATTERY_VOLTAGE = 3.00; // (volts)
const unsigned long LOW_BATTERY_SLEEP_INTERVAL      = 30;  // (minutes)
const unsigned long VERY_LOW_BATTERY_SLEEP_INTERVAL = 120; // (minutes)

// LANGUAGE
// see config.h

// UNITS
// see config.h

// AIR QUALITY INDEX
// see config.h

// WIND
// see config.h

lmarzen, 2023-02-10:
Thank you. I will see if I can reproduce your issue later this evening.

lmarzen, 2023-02-11:
I was not able to reproduce the issue, but I think is possible that it could have been buffer size. I actually have some api responses that I saved as examples when I was experimenting months ago when I was first programming this project, one of the responses I saved had a size of 35.2kb. I increased the buffer size from 32kb to 48kb. Not sure if that will fix your issue.

lmarzen, 2023-02-11:
You can try increasing the timeout to 10s (default 1s) by adding `json.setTimeout(10000);` to line 9 of api_response.cpp at the beginning of deserializeOneCall().

nglessner, 2023-02-11:
What I'm seeing is very slow incoming data from api.openweathermap.org, but I think the speed issue is related to my MCU. Is the platformio.ini in main up to date?

I used the suggested StreamUtils package to output the wifi client stream to serial and I would see the data arrive very slowly in chunks.  After updating the platformio.ini to use the latest platform and lib_deps I would get a significantly faster wifi connection (both establishing connection and data incoming), but I would also get this I2C error:

[esp32-hal-i2c-slave.c:224] i2cSlaveInit(): invalid pins sda=16, scl=-96
[  3411][E][Wire.cpp:167] begin(): Slave Init ERROR

I'm still fiddling with the library versions trying to figure out which combination will work for me.  If I have it set to the config below, it will give me the IncompleteInput error.  If I change the platform = espressif32 @ 4.4.0, wifi will run fast but I will get the i2cSlaveInit error.

[env:firebeetle32]
platform = espressif32 @ 4.0.0
board = firebeetle32
framework = arduino
lib_deps =
	bblanchon/ArduinoJson
	zinggjm/GxEPD2 @ ^1.4.5
	adafruit/Adafruit Unified Sensor @ ^1.1.5
	adafruit/Adafruit BusIO @ ^1.11.2
	adafruit/Adafruit BME280 Library @ ^2.2.2
	bblanchon/StreamUtils@^1.7.0
monitor_speed = 115200
board_build.f_cpu = 160000000L

lmarzen, 2023-02-11:
There is an open issue https://github.com/platformio/platform-espressif32/issues/644 to add official support for the firebeetle esp32-e into platformio. Until then, it seems we are stuck on this older version (4.0.0.) 5.1 won't even let you upload to the code, you get a bootloader error. I too saw I2C errors after versions 4.0.

lmarzen, 2023-02-11:
To give you more insight, I only recently added @ 4.0.0 to the .ini file. When I originally built this in the summer of 2022 I did not specify the version of platform espressif32, (presumably I was using the latest stable version). Then when I tried to rebuild the same code again in December of 2022 I discovered that the new versions of espressif32 broke compatibility with the firebeetle esp32-e. I had no idea this board wasn't officially supported yet.

lmarzen, 2023-02-11:
I found the change that I suspect broke the esp32-e's compatibility; these changes in firebeetle32.json. https://github.com/platformio/platform-espressif32/commit/cb3583813d0dad75edc0853cfec865c89b221263. I can experiment some tomorrow. I'm tempted to create a pull request to add a firebeetle32e board for platformio.

lmarzen, 2023-02-11:
In order to upload code to the Firebeetle 2 ESP32-E using the latest version of espressif32, we can override 3 of the default settings for the firebeetle32 board configuration. See my platformio.ini file below. I already updated the repo with these changes (https://github.com/lmarzen/esp32-weather-epd/commit/5bed202f4725047fa3a9c57d04c9c60c8765b069). I immediately noticed that my esp32-e connects to wifi much faster on the latest espressif32. This makes me hopeful that we may have solved your problem.
```
[env:firebeetle32]
platform = espressif32
board = firebeetle32
framework = arduino

; override default settings to enable compatibility with Firebeetle 2 ESP32-E
board_upload.flash_size = 4MB
board_upload.maximum_ram_size = 327680
board_upload.maximum_size = 4194304
```

nglessner, 2023-02-11:
This worked! What pointed you towards fixing the flash size?  I'm also curious what made you undo the change to fix the ram size? DFRobots spec says 520KB, but it looks like I'm limited to the 320KB that was built into the original ESP32 spec.

lmarzen, 2023-02-11:
When you try to upload to the esp32-e with the latest platform = espressif32, it gives an error about the flash size being incorrect. This was my first indication. Since I knew that the older versions of espressif32 worked, I looked into what had changed for the firebeetle32 board definition. I found this specific commit that I suspect broke the compatibility, https://github.com/platformio/platform-espressif32/commit/cb3583813d0dad75edc0853cfec865c89b221263.

I reverted the explicit override for ram size because the "firebeetle32" board definition was already using 520KB. So my override to 520KB was pointless. If what you are saying is true, do you think we need to limit it to 320KB?

I also have moved to add official support for the firebeetle 2 esp32-e to arduino-esp32 and platformio. (https://github.com/espressif/arduino-esp32/pull/7835 and https://github.com/platformio/platform-espressif32/pull/1026)

Closed 2023-02-13.

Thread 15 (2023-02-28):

Receive error when uploading to FireBeetle from USB

NWstudent, 2023-02-28:
....
.....
Uploading .pio/build/firebeetle32/firmware.bin
esptool.py v4.4
Serial port /dev/cu.Bluetooth-Incoming-Port
Connecting......................................

A fatal error occurred: Failed to connect to ESP32: No serial data received.
For troubleshooting steps visit: https://docs.espressif.com/projects/esptool/en/latest/troubleshooting.html
*** [upload] Error 2

lmarzen, 2023-03-01:
This is likely an issue with drivers. You would need to share more information if you want help diagnosing this. Check out the troubleshooting link that is in the output you shared. This issue does not seem to be uncommon. Try googling the error. There are many conversations about it online with steps you can take to resolve it.

NWstudent, 2023-03-07:
I have attempted to install both recommend drivers for Mac (Apple M1 Max) OS (Ventura-13.2.1). Have attempted to install using VScode and Arduino IDE. I have attempted with 2 FireBeetle boards (p/n:DFR0654), two cables, two usb-c ports to rule out hardware malfunction. I also attempted to upload to a wired board and a clean board to determine if it had to be built out prior to upload. Each time the process gets the point where it performs:

Serial port /dev/cu.Bluetooth-Incoming-Port
Connecting......................................

and then shows:

A fatal error occurred: Failed to connect to ESP32: No serial data received.
For troubleshooting steps visit: https://docs.espressif.com/projects/esptool/en/latest/troubleshooting.html
*** [upload] Error 2
=================================== [FAILED] Took 44.78 seconds ===================================

 *  The terminal process "platformio 'run', '--target', 'upload'" terminated with exit code: 1.
 *  Terminal will be reused by tasks, press any key to close it.

The same exact process happens if I attempt to run the upload with nothing attached to the computer. Once the recommended drivers were installed the Mac recognizes the board as a USB Serial:

  Product ID:	0x7522
  Vendor ID:	0x1a86
  Version:	2.64
  Speed:	Up to 12 Mb/s
  Location ID:	0x02100000 / 1
  Current Available (mA):	500
  Extra Operating Current (mA):	0

Full output of the install is:

Executing task: platformio run --target upload

Processing firebeetle32 (platform: espressif32; board: firebeetle32; framework: arduino)
----------------------------------------------------------------------------------------------------
Verbose mode can be enabled via `-v, --verbose` option
CONFIGURATION: https://docs.platformio.org/page/boards/espressif32/firebeetle32.html
PLATFORM: Espressif 32 (6.0.1) > FireBeetle-ESP32
HARDWARE: ESP32 80MHz, 520KB RAM, 4MB Flash
DEBUG: Current (cmsis-dap) External (cmsis-dap, esp-bridge, esp-prog, iot-bus-jtag, jlink, minimodule, olimex-arm-usb-ocd, olimex-arm-usb-ocd-h, olimex-arm-usb-tiny-h, olimex-jtag-tiny, tumpa)
PACKAGES:
 - framework-arduinoespressif32 @ 3.20006.221224 (2.0.6)
 - tool-esptoolpy @ 1.40400.0 (4.4.0)
 - tool-mkfatfs @ 2.0.1
 - tool-mklittlefs @ 1.203.210628 (2.3)
 - tool-mkspiffs @ 2.230.0 (2.30)
 - toolchain-xtensa-esp32 @ 8.4.0+2021r2-patch5
LDF: Library Dependency Finder -> https://bit.ly/configure-pio-ldf
LDF Modes: Finder ~ chain, Compatibility ~ soft
Found 40 compatible libraries
Scanning dependencies...
Dependency Graph
|-- ArduinoJson @ 6.20.1
|-- GxEPD2 @ 1.5.0
|   |-- Adafruit GFX Library @ 1.11.5
|   |   |-- Adafruit BusIO @ 1.14.1
|   |   |   |-- Wire @ 2.0.0
|   |   |   |-- SPI @ 2.0.0
|   |   |-- Wire @ 2.0.0
|   |   |-- SPI @ 2.0.0
|   |-- Adafruit BusIO @ 1.14.1
|   |   |-- Wire @ 2.0.0
|   |   |-- SPI @ 2.0.0
|   |-- Wire @ 2.0.0
|   |-- SPI @ 2.0.0
|-- Adafruit Unified Sensor @ 1.1.7
|-- Adafruit BusIO @ 1.14.1
|   |-- Wire @ 2.0.0
|   |-- SPI @ 2.0.0
|-- Adafruit BME280 Library @ 2.2.2
|   |-- Adafruit BusIO @ 1.14.1
|   |   |-- Wire @ 2.0.0
|   |   |-- SPI @ 2.0.0
|   |-- Wire @ 2.0.0
|   |-- SPI @ 2.0.0
|   |-- Adafruit Unified Sensor @ 1.1.7
|-- pollutant-concentration-to-aqi
|-- HTTPClient @ 2.0.0
|   |-- WiFi @ 2.0.0
|   |-- WiFiClientSecure @ 2.0.0
|   |   |-- WiFi @ 2.0.0
|-- SPI @ 2.0.0
|-- WiFi @ 2.0.0
|-- Preferences @ 2.0.0
|-- Wire @ 2.0.0
Building in release mode
Retrieving maximum program size .pio/build/firebeetle32/firmware.elf
Checking size .pio/build/firebeetle32/firmware.elf
Advanced Memory Usage is available via "PlatformIO Home > Project Inspect"
RAM:   [==        ]  18.9% (used 100500 bytes from 532480 bytes)
Flash: [========= ]  92.9% (used 1217337 bytes from 1310720 bytes)
Configuring upload protocol...
AVAILABLE: cmsis-dap, esp-bridge, esp-prog, espota, esptool, iot-bus-jtag, jlink, minimodule, olimex-arm-usb-ocd, olimex-arm-usb-ocd-h, olimex-arm-usb-tiny-h, olimex-jtag-tiny, tumpa
CURRENT: upload_protocol = esptool
Looking for upload port...
Auto-detected: /dev/cu.Bluetooth-Incoming-Port
Uploading .pio/build/firebeetle32/firmware.bin
esptool.py v4.4
Serial port /dev/cu.Bluetooth-Incoming-Port
Connecting......................................

A fatal error occurred: Failed to connect to ESP32: No serial data received.
For troubleshooting steps visit: https://docs.espressif.com/projects/esptool/en/latest/troubleshooting.html
*** [upload] Error 2
=================================== [FAILED] Took 44.90 seconds ===================================

 *  The terminal process "platformio 'run', '--target', 'upload'" terminated with exit code: 1.
 *  Terminal will be reused by tasks, press any key to close it.

lmarzen, 2023-03-07:
This issue isn't specific to this project.  I have not encountered this issue myself, my only meaningful suggestion is to try what is mentioned on other forums. It sounds like you are on the right track though. I would disconnect everything from the esp32 when troubleshooting this issue, as it is a known issue that an incorrectly wired spi bus can cause some connection issues. I would also try another cable and different ports on your computer. Maybe even try on a different computer if you have one available.

Closed 2023-03-05.

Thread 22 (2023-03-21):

Error compile VS Studio

ParsonsGrahamJ, 2023-03-21:
Great project I am awaiting FireBeetle32 on order from China. I decided to configure and compile ready to upload once I get the board.

Getting an error from VS Code with one of the parameters.

src/main.cpp: In function 'void beginDeepSleep(long unsigned int&, tm*)':
src/main.cpp:105:58: error: call of overloaded 'String(uint64_t&)' is ambiguous
   Serial.println("Deep-sleep for " + String(sleepDuration) + "s");

VS Code flags these String(sleepDuration)

  esp_sleep_enable_timer_wakeup(sleepDuration * 1000000ULL);
  Serial.println("Awake for " + String((millis() - startTime) / 1000.0, 3) + "s");
*  Serial.println("Deep-sleep for " + String(sleepDuration) + "s"); *
  esp_deep_sleep_start();
} // end beginDeepSleep

* line 105 in code

Any idea on fix ?

Thank you again for this great project, going to look at integrating outside ESP32 with temp/humd/Pressure sensor I already have over ESP-now. See if its possible.

Regards,

Graham

lmarzen, 2023-03-21:
Not an issue for me, but I just updated the project with a small change that should fix this error for you. Let me know if it works now.

ParsonsGrahamJ, 2023-03-21:
Wow that was a quick response Luke, I am impressed.

I did search for the reference to sleep Duration and suspected an issue with declaration. Unfortunately it still wont compile same error line.

Here is the full list output from VS Code

src/main.cpp: In function 'void beginDeepSleep(long unsigned int&, tm*)':
src/main.cpp:105:58: error: call of overloaded 'String(long long unsigned int&)' is ambiguous
   Serial.println("Deep-sleep for " + String(sleepDuration) + "s");
                                                          ^
In file included from C:/Users/Graham/.platformio/packages/framework-arduinoespressif32/cores/esp32/Arduino.h:159,
                 from src/main.cpp:18:
C:/Users/Graham/.platformio/packages/framework-arduinoespressif32/cores/esp32/WString.h:75:18: note: candidate: 'String::String(double, unsigned int)'
         explicit String(double, unsigned int decimalPlaces = 2);
                  ^~~~~~
C:/Users/Graham/.platformio/packages/framework-arduinoespressif32/cores/esp32/WString.h:74:18: note: candidate: 'String::String(float, unsigned int)'
         explicit String(float, unsigned int decimalPlaces = 2);
                  ^~~~~~
C:/Users/Graham/.platformio/packages/framework-arduinoespressif32/cores/esp32/WString.h:73:18: note: candidate: 'String::String(long unsigned int, unsigned char)'
         explicit String(unsigned long, unsigned char base = 10);
                  ^~~~~~
C:/Users/Graham/.platformio/packages/framework-arduinoespressif32/cores/esp32/WString.h:72:18: note: candidate: 'String::String(long int, unsigned char)'
         explicit String(long, unsigned char base = 10);
                  ^~~~~~
C:/Users/Graham/.platformio/packages/framework-arduinoespressif32/cores/esp32/WString.h:71:18: note: candidate: 'String::String(unsigned int, unsigned char)'
         explicit String(unsigned int, unsigned char base = 10);
                  ^~~~~~
C:/Users/Graham/.platformio/packages/framework-arduinoespressif32/cores/esp32/WString.h:70:18: note: candidate: 'String::String(int, unsigned char)'
         explicit String(int, unsigned char base = 10);
                  ^~~~~~
C:/Users/Graham/.platformio/packages/framework-arduinoespressif32/cores/esp32/WString.h:69:18: note: candidate: 'String::String(unsigned char, unsigned char)'
         explicit String(unsigned char, unsigned char base = 10);
                  ^~~~~~
C:/Users/Graham/.platformio/packages/framework-arduinoespressif32/cores/esp32/WString.h:68:18: note: candidate: 'String::String(char)'         explicit String(char c);
                  ^~~~~~
C:/Users/Graham/.platformio/packages/framework-arduinoespressif32/cores/esp32/WString.h:66:9: note: candidate: 'String::String(StringSumHelper&&)'
         String(StringSumHelper &&rval);
         ^~~~~~
C:/Users/Graham/.platformio/packages/framework-arduinoespressif32/cores/esp32/WString.h:65:9: note: candidate: 'String::String(String&&)'
         String(String &&rval);
         ^~~~~~
C:/Users/Graham/.platformio/packages/framework-arduinoespressif32/cores/esp32/WString.h:62:9: note: candidate: 'String::String(const String&)'
         String(const String &str);
         ^~~~~~
*** [.pio\build\firebeetle32\src\main.cpp.o] Error 1

Graham

lmarzen, 2023-03-21:
Hi Graham. This is interesting.

It looks like you don't have a definition in your WString.h for unsigned long long. This was added in February of this year: https://github.com/espressif/arduino-esp32/blob/master/cores/esp32/WString.h

Can you tell me what versions you see for framework-arduinoespressif32 when you build?

It should say something like this...

> PACKAGES:
>   \- framework-arduinoespressif32 @ 3.20005.220925 (2.0.5)

ParsonsGrahamJ, 2023-03-21:
Me again,

I had a look at the library WString.h and could not see a reference for a "unsigned long long" I did see a reference for "unsigned long".

Just changed it to "unsigned long sleepDuration = 0;" and it worked. Now compiles completely.

Will keep you posted once I complete the build. Will see if I can intergrate a remote sensor for real time outside temp/humd/pressure.

ParsonsGrahamJ, 2023-03-21:
Here is a copy of the WString references I have

        explicit String(char c);
        explicit String(unsigned char, unsigned char base = 10);
        explicit String(int, unsigned char base = 10);
        explicit String(unsigned int, unsigned char base = 10);
        explicit String(long, unsigned char base = 10);
        explicit String(unsigned long, unsigned char base = 10);
        explicit String(float, unsigned int decimalPlaces = 2);
        explicit String(double, unsigned int decimalPlaces = 2);
        ~String(void);

lmarzen, 2023-03-21:
Yes, looks like you may be on an older version of framework-arduinoespressif32. I'm not sure why platformio is not automatically getting the latest version.

ParsonsGrahamJ, 2023-03-21:
VS Code is still very buggy and a real pain when building code. Had lots of issues with some WLED projects and libraries not downloading the latest. The guys that write the code for WLED have also had issues with some people not getting the current updates, its hit and miss.

framework-arduinoespressif32 @ 3.20003.220613 (2.0.3)

Just clicked the update and it said is up to date, so an issue with VS Code, hope that helps but it worked with the above and compiled, so hope it works once I get all the hardware together.

ParsonsGrahamJ, 2023-03-21:
Thank you so much for the help looks the the issue was indeed the PlatformIO not updating.

Looked at there forum PlatformIO and looks like others have had issues. Have manual updated both ESP32 and ESP8266 as they were out of date and compiled with your original code no issues.

Learn something new every day, here is the manual update method,

**PlatformIO will install the latest Arduino Core for ESP32 from https://github.com/espressif/arduino-esp32. The [Git](https://git-scm.com/) should be installed in a system. To update Arduino Core to the latest revision, please open [PlatformIO IDE](https://docs.platformio.org/en/latest/integration/ide/pioide.html#pioide) and navigate to PlatformIO Home > Platforms > Updates.**

It updated all the outdated version with the above.

Will keep you posted once complete hardware

Thanks again Graham

lmarzen, 2023-03-21:
Thank you for sharing the solution. Good luck with your project and integrating esp-now, sounds like an exciting project.

lmarzen, 2023-03-21:
I discovered that I can specify the version of the espressif framework to use in the platformio.ini file. This should prevent issues like this in the future. I will add this. Thanks again Graham.

lmarzen, 2023-03-21:
e2979d7

ParsonsGrahamJ, 2023-03-21:
Yes on the same link from the PlatformIO it does say you can force versioning within the PlatformIO.ini file. It is still annoying that this is not done with the usual update method on PlatformIO. Been court out a few times with version on PlatformIO. When I updated both the ESP32 and ESP8266 I had lots of other programs started behaving correctly too on compile. Completely forgot about checking if it was updated. Learn something new.

lmarzen, 2023-03-21:
I agree. I would have expected that PlatformIO would have automatically checked for updates for project dependencies.

Closed 2023-03-21.

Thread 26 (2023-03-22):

Compile error " no such file pins_arduino.h"

coldfire100, 2023-03-22:
Hi Luke
First off, great project nice work! One problem I can't seem to get around is the error
"fatal error: pins_arduino.h: No such file or director"
I cloned the project from Github and have the latest files and platformio.ini. Any suggestions on where to look for this.

I can post the full output from the build if needed.

I'm pretty new at VsCode and PlatformIO so any help would be much appreciated.

Thanks

Mark

lmarzen, 2023-03-23:
Hi Mark,

Yeah go ahead and share your full output. Additionally, can you confirm what esp32 board you are using?

-Luke

coldfire100, 2023-03-23:
Hi Luke
Sorry for the late response. The board the is DF Robot Firebeetle2. I have 2 on order. This is a clone of your project. I didn't change anything in the settings. Below is the output from the build.

Executing task: C:\Users\ZZZ\.platformio\penv\Scripts\platformio.exe run

Processing dfrobot_firebeetle2_esp32e (board: dfrobot_firebeetle2_esp32e; platform: espressif32 @ 6.1.0; framework: arduino)
---------------------------------------------------------------------------------------------------------------------------------------------------------------------------------Verbose mode can be enabled via `-v, --verbose` option
CONFIGURATION: https://docs.platformio.org/page/boards/espressif32/dfrobot_firebeetle2_esp32e.html
PLATFORM: Espressif 32 (6.1.0) > DFRobot Firebeetle 2 ESP32-E
HARDWARE: ESP32 80MHz, 320KB RAM, 4MB Flash
DEBUG: Current (cmsis-dap) External (cmsis-dap, esp-bridge, esp-prog, iot-bus-jtag, jlink, minimodule, olimex-arm-usb-ocd, olimex-arm-usb-ocd-h, olimex-arm-usb-tiny-h, olimex-jtag-tiny, tumpa)
PACKAGES:
 - framework-arduinoespressif32 @ 3.20007.0 (2.0.7)
 - tool-esptoolpy @ 1.40500.0 (4.5.0)
 - toolchain-xtensa-esp32 @ 8.4.0+2021r2-patch5
LDF: Library Dependency Finder -> https://bit.ly/configure-pio-ldf
LDF Modes: Finder ~ chain, Compatibility ~ soft
Found 40 compatible libraries
Scanning dependencies...
Dependency Graph
|-- Adafruit BME280 Library @ 2.2.2
|   |-- Adafruit BusIO @ 1.14.1
|   |   |-- Wire @ 2.0.0
|   |   |-- SPI @ 2.0.0
|   |-- Wire @ 2.0.0
|   |-- SPI @ 2.0.0
|   |-- Adafruit Unified Sensor @ 1.1.9
|-- Adafruit BusIO @ 1.14.1
|   |-- Wire @ 2.0.0
|   |-- SPI @ 2.0.0
|-- Adafruit Unified Sensor @ 1.1.9
|-- ArduinoJson @ 6.21.0
|-- GxEPD2 @ 1.5.0
|   |-- Adafruit GFX Library @ 1.11.5
|   |   |-- Adafruit BusIO @ 1.14.1
|   |   |   |-- Wire @ 2.0.0
|   |   |   |-- SPI @ 2.0.0
|   |   |-- Wire @ 2.0.0
|   |   |-- SPI @ 2.0.0
|   |-- Adafruit BusIO @ 1.14.1
|   |   |-- Wire @ 2.0.0
|   |   |-- SPI @ 2.0.0
|   |-- Wire @ 2.0.0
|   |-- SPI @ 2.0.0
|-- pollutant-concentration-to-aqi
|-- HTTPClient @ 2.0.0
|   |-- WiFi @ 2.0.0
|   |-- WiFiClientSecure @ 2.0.0
|   |   |-- WiFi @ 2.0.0
|-- SPI @ 2.0.0
|-- WiFi @ 2.0.0
|-- Preferences @ 2.0.0
|-- Wire @ 2.0.0
Building in release mode
Compiling .pio\build\dfrobot_firebeetle2_esp32e\src\_strftime.cpp.o
Compiling .pio\build\dfrobot_firebeetle2_esp32e\src\api_response.cpp.o
In file included from C:/Users/ZZZ/.platformio/packages/framework-arduinoespressif32/cores/esp32/esp32-hal.h:79,
                 from C:/Users/ZZZ/.platformio/packages/framework-arduinoespressif32/cores/esp32/Arduino.h:36,
                 from include/_locale.h:22,
                 from src/_strftime.cpp:29:
C:/Users/ZZZ/.platformio/packages/framework-arduinoespressif32/cores/esp32/esp32-hal-gpio.h:29:10: fatal error: pins_arduino.h: No such file or directory

**********************************************************************
* Looking for pins_arduino.h dependency? Check our library registry!
*
* CLI  > platformio lib search "header:pins_arduino.h"
* Web  > https://registry.platformio.org/search?q=header:pins_arduino.h
*
**********************************************************************

 #include "pins_arduino.h"
          ^~~~~~~~~~~~~~~~
compilation terminated.
Compiling .pio\build\dfrobot_firebeetle2_esp32e\src\client_utils.cpp.o
Compiling .pio\build\dfrobot_firebeetle2_esp32e\src\config.cpp.o
In file included from C:/Users/ZZZ/.platformio/packages/framework-arduinoespressif32/cores/esp32/esp32-hal.h:79,
                 from C:/Users/ZZZ/.platformio/packages/framework-arduinoespressif32/cores/esp32/Arduino.h:36,
                 from .pio/libdeps/dfrobot_firebeetle2_esp32e/ArduinoJson/src/ArduinoJson.hpp:17,
                 from .pio/libdeps/dfrobot_firebeetle2_esp32e/ArduinoJson/src/ArduinoJson.h:9,
                 from src/api_response.cpp:19:
C:/Users/ZZZ/.platformio/packages/framework-arduinoespressif32/cores/esp32/esp32-hal-gpio.h:29:10: fatal error: pins_arduino.h: No such file or directory

**********************************************************************
* Looking for pins_arduino.h dependency? Check our library registry!
*
* CLI  > platformio lib search "header:pins_arduino.h"
* Web  > https://registry.platformio.org/search?q=header:pins_arduino.h
*
**********************************************************************

 #include "pins_arduino.h"
          ^~~~~~~~~~~~~~~~
compilation terminated.
In file included from C:/Users/ZZZ/.platformio/packages/framework-arduinoespressif32/cores/esp32/esp32-hal.h:79,
                 from C:/Users/ZZZ/.platformio/packages/framework-arduinoespressif32/cores/esp32/Arduino.h:36,
                 from src/client_utils.cpp:23:
C:/Users/ZZZ/.platformio/packages/framework-arduinoespressif32/cores/esp32/esp32-hal-gpio.h:29:10: fatal error: pins_arduino.h: No such file or directory

**********************************************************************
* Looking for pins_arduino.h dependency? Check our library registry!
*
* CLI  > platformio lib search "header:pins_arduino.h"
* Web  > https://registry.platformio.org/search?q=header:pins_arduino.h
*
**********************************************************************

 #include "pins_arduino.h"
          ^~~~~~~~~~~~~~~~
compilation terminated.
In file included from C:/Users/ZZZ/.platformio/packages/framework-arduinoespressif32/cores/esp32/esp32-hal.h:79,
                 from C:/Users/ZZZ/.platformio/packages/framework-arduinoespressif32/cores/esp32/Arduino.h:36,
                 from src/config.cpp:19:
C:/Users/ZZZ/.platformio/packages/framework-arduinoespressif32/cores/esp32/esp32-hal-gpio.h:29:10: fatal error: pins_arduino.h: No such file or directory

**********************************************************************
* Looking for pins_arduino.h dependency? Check our library registry!
*
* CLI  > platformio lib search "header:pins_arduino.h"
* Web  > https://registry.platformio.org/search?q=header:pins_arduino.h
*
**********************************************************************

 #include "pins_arduino.h"
          ^~~~~~~~~~~~~~~~
compilation terminated.
Compiling .pio\build\dfrobot_firebeetle2_esp32e\src\display_utils.cpp.o
Compiling .pio\build\dfrobot_firebeetle2_esp32e\src\locales\locale_en_gb.cpp.o
*** [.pio\build\dfrobot_firebeetle2_esp32e\src\_strftime.cpp.o] Error 1
*** [.pio\build\dfrobot_firebeetle2_esp32e\src\api_response.cpp.o] Error 1
*** [.pio\build\dfrobot_firebeetle2_esp32e\src\client_utils.cpp.o] Error 1
*** [.pio\build\dfrobot_firebeetle2_esp32e\src\config.cpp.o] Error 1
In file included from C:/Users/ZZZ/.platformio/packages/framework-arduinoespressif32/cores/esp32/esp32-hal.h:79,
                 from C:/Users/ZZZ/.platformio/packages/framework-arduinoespressif32/cores/esp32/Arduino.h:36,
                 from src/display_utils.cpp:20:
C:/Users/ZZZ/.platformio/packages/framework-arduinoespressif32/cores/esp32/esp32-hal-gpio.h:29:10: fatal error: pins_arduino.h: No such file or directory

**********************************************************************
* Looking for pins_arduino.h dependency? Check our library registry!
*
* CLI  > platformio lib search "header:pins_arduino.h"
* Web  > https://registry.platformio.org/search?q=header:pins_arduino.h
*
**********************************************************************

 #include "pins_arduino.h"
          ^~~~~~~~~~~~~~~~
compilation terminated.
*** [.pio\build\dfrobot_firebeetle2_esp32e\src\display_utils.cpp.o] Error 1
In file included from C:/Users/ZZZ/.platformio/packages/framework-arduinoespressif32/cores/esp32/esp32-hal.h:79,
                 from C:/Users/ZZZ/.platformio/packages/framework-arduinoespressif32/cores/esp32/Arduino.h:36,
                 from include/config.h:23,
                 from src/locales/locale_en_gb.cpp:18:
C:/Users/ZZZ/.platformio/packages/framework-arduinoespressif32/cores/esp32/esp32-hal-gpio.h:29:10: fatal error: pins_arduino.h: No such file or directory

**********************************************************************
* Looking for pins_arduino.h dependency? Check our library registry!
*
* CLI  > platformio lib search "header:pins_arduino.h"
* Web  > https://registry.platformio.org/search?q=header:pins_arduino.h
*
**********************************************************************

 #include "pins_arduino.h"
          ^~~~~~~~~~~~~~~~
compilation terminated.
*** [.pio\build\dfrobot_firebeetle2_esp32e\src\locales\locale_en_gb.cpp.o] Error 1
========================================================================= [FAILED] Took 260.67 seconds =========================================================================

Environment                 Status    Duration
--------------------------  --------  ------------
dfrobot_firebeetle2_esp32e  FAILED    00:04:20.669
===================================================================== 1 failed, 0 succeeded in 00:04:20.669 =====================================================================
 *  The terminal process "C:\Users\ZZZ\.platformio\penv\Scripts\platformio.exe 'run'" terminated with exit code: 1.
 *  Terminal will be reused by tasks, press any key to close it.

I have your latest platformio.ini file. Not sure if anything else needs to be updated.
If you could take a look at this.

Thanks

Mark

lmarzen, 2023-03-26:
hmmm.. can you see if there are any updates for arduino core or espressif, etc?
> Navigate to PlatformIO Home > Platforms > Updates.

coldfire100, 2023-03-26:
Hi Luke
I did a bit of research and found a reference to the "arduino.pins.h" error. The suggestions was to delete the folders in the
user/.platformio/packages that referenced the esp32.

I wound up deleting the folders:

framework-arduinoespressif32@3.10004.210126
tool-esptoolpy
framework-arduinoespressif32
toolchain-xtensa-esp32@8.4.0+2021r2-patch5

I did a clean and rebuild. Lo and behold it compiled without the errors. Any idea why this would have worked?

Anyway,  I don't have the boards in yet to test it. They should be here in a couple of weeks.
Hopefully all will work.

Thanks for looking into this.

Mark

lmarzen, 2023-03-26:
No idea. Sounds like platformio being buggy, smh. Glad to hear you were able to resolve your issue.

Closed 2023-03-26.

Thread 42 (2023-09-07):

Waveshare e-Paper Driver HAT rev2.3

Spanholz, 2023-09-07:
I got a new 7.5 3-colour display from Waveshare this week including a Waveshare e-Paper Driver HAT rev2.3. The new HAT is not documented on Waveshares webpage yet and is different from the previous versions. It features 9 pins, with an additional PWR pin. The display does not start with VCC or PWR only connected. But with PWR connected to second 3.3V and therefore disconnecting the BME it works. I will update if the PWR pin can be put on same 3V3 as the VCC from the hat.

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

Spanholz, 2023-09-07:
Putting PWR and VCC on the same 3V3 pin works. The other PIN can than be used by BME

lmarzen, 2023-09-09:
Thanks for investigating and documenting this.

I just found this page talking about the changes...
https://www.waveshare.net/wiki/E-Paper_Driver_HAT

Translating to english...

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

Appears you are right to connect PWR to 3.3V. I'll keep an eye on the epaper driver library this project uses and see if they provide any updates.

nonpayer, 2023-09-30:
I apologize, but I'm a beginner. I also received the Waveshare e-Paper Driver HAT rev2.3. I'm doing something wrong, because when I upload, I have 141 problems in renderer.app. Can anyone help me as a complete beginner? I followed the instructions, but I probably have something wrongly connected because I have HAT rev 2.3. and there is another in the manual...
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

lmarzen, 2023-09-30:
If you are getting a lot of problems in renderer.cpp, your config.h file may be misconfigured.

lmarzen, 2023-09-30:
Additionally can you share the exact model of panel you are using as well as the model of esp32 to make it easier to assist in troubleshooting.

nonpayer, 2023-09-30:
800×480, 7.5inch E-Ink display HAT for Raspberry Pi and e-Paper Driver HAT ver 2.3 with 9 pins, with an additional PWR pin.

FireBeetle 2 ESP32-E

Update is success without error, but i have only black edges on the display...

lmarzen, 2023-09-30:
Try reverting your config.h back to the default.

nonpayer, 2023-10-02:
Thanks for advice. I tried to use the default config.h and the upload was successful. But I have a 9-pin HAT and with an additional PWR pin. As Spanholz already wrote, the display only works with PWR connected to second 3.3V and therefore disconnecting the BME, or PWR and VCC on the same 3V3. But how do I plug PWR and 3V3 into the same connector. ?

lmarzen, 2023-10-02:
You will need to make a splitter. or solder both wires to the same 3v on the esp32

sonett12, 2023-10-03:
first of all thank you very much for your project @lmarzen I got myself the same hardware and have it running a few days now, works like a charm :-)

I also got the rev2.3 e-paper hat with this additional pwr pin to enable the display. I looked it up in the schematic here
https://files.waveshare.com/upload/8/8e/E-Paper_Driver_HAT.pdf

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

For my understanding the additional pin can be controlled to activate/disable the display but is not powering the display, so I just used a GPIO pin for this, I connected the pwr pin to D6 pin 14 and added the activation in the main.ccp as such (lines 318..320 + 335):

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

for me that was enough, maybe others you can do so as well. Could be nice to have it an option in the project source code to configure this pwr pin as well.

nonpayer, 2023-10-03:
> You will need to make a splitter. or solder both wires to the same 3v on the esp32

I did it and everything works fine. Thanks for help.

lmarzen, 2023-10-03:
@sonett12 Thanks for investigating this further and sharing your results. I'll be adding an option for this and adding some documentation when I get a chance.

Marckau, 2023-10-13:
I tried the @sonett12 code and hooked the power pin to the D6 and updated the code as well as just soldering both the VCC and PWR on the 3V3 line. Same result the screen works and displays all the correct information for a brief moment then goes black. Any idea why? I have the black and red display.
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

lmarzen, 2023-11-19:
I have suggested users purchase the DESPI-CO2 adaptor board instead of the waveshare hat going forward.

nicoh88, 2024-06-06:
> the pwr pin to D6 pin 14

Hi @sonett12, you say you would use the **D6 / 14** for the new e-Paper HAT rev2.3 for the additional **PIN PWR**.

According to the [wiring diagram](https://github.com/lmarzen/esp32-weather-epd/blob/main/showcase/wiring_diagram_waveshare_rev22.png) from lmarzen, **D6 / 14** is already used for **BUSY**. **Do you then not use BUSY at all or how did you do it?**

I actually wanted to use **D9 / 2** for PWR, but according to the documentation of the[ FireBeetle Board ESP32-E (SKU DFR0654)](https://wiki.dfrobot.com/FireBeetle_Board_ESP32_E_SKU_DFR0654) D9 / 2 has a remark: "_For controlling onboard LED by outputting digital signal_"

Hence my question about what you did with BUSY.
Thank you in advance for your answer.

Closed 2023-11-19.

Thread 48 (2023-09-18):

Partial refresh support

Velkas, 2023-09-18:
I just got all the components (finally!) and got my own unit working as expected and customized for my location/preferences.

Works great!

I was doing some poking around and am having trouble understanding how to get partial refresh working. I was hoping to further enhance that low power goals of this project by preventing the full refresh which takes multiple seconds to occur as it flashes the full screen multiple times to redraw.

I know my panel supports partial refresh according to the spec, but it seems like nothing I change in the display init flow makes any difference -- I still get the full refresh every time.

I have been searching around and have run into dead ends. Are there any resources available or hints as to where I can investigate further in an attempt to implement this?

lmarzen, 2023-09-18:
I remember investigating the partial refresh back 2 years ago or so. There are some examples in the GxEPD2 epaper driver library repository.

I only experimented with the GxEPD2 library. I was able to get partial refreshes working however when the esp32 goes into deep sleep and wakes up again you must reinitialize the screen with a full refresh before you can draw any partial refreshes.

lmarzen, 2023-09-18:
I think it would be preferable to use partial refreshes as you suggest with the occasional full refresh to clean up ghosting effects, but I never implemented it since I wasn't able to get the partial refreshes to happen without a full refresh after deep sleep. It may be possible to get working correctly (i don't know). Definitely something worth revisiting. Let me know if you find anything interesting.

lmarzen, 2023-09-18:
> I know my panel supports partial refresh according to the spec, but it seems like nothing I change in the display init flow makes any difference -- I still get the full refresh every time.

This is the same issue I ran into and was describing in my earlier replies.

Velkas, 2023-09-18:
Thank you for the info, I'll continue digging!

> ... however when the esp32 goes into deep sleep and wakes up again you must reinitialize the screen with a full refresh before you can draw any partial refreshes.

I do wonder, can you elaborate more on why you think this was? I suspect I was running into the same thing. One of the things I thought about trying was to write more state to non-volatile storage as a means of getting around some of the deep-sleep / wakeup limitations. Space is quite limited but at the very least it could help to reduce the amount of elements that need to be refreshed (assuming partial refresh is working).

lmarzen, 2023-09-18:
Not sure the exact reason.

Check out the init documentation from the driver library
https://github.com/ZinggJM/GxEPD2/blob/master/src/GxEPD2_BW.h

This seems to imply that the display must remain powered when esp32 is in deep sleep to avoid full refresh.

'''
    // init method with additional parameters:
    // initial false for re-init after processor deep sleep wake up, if display power supply was kept
    // this can be used to avoid the repeated initial full refresh on displays with fast partial update
    // NOTE: garbage will result on fast partial update displays, if initial full update is omitted after power loss
    // reset_duration = 10 is default; a value of 2 may help with "clever" reset circuit of newer boards from Waveshare
    // pulldown_rst_mode true for alternate RST handling to avoid feeding 5V through RST pin
    void init(uint32_t serial_diag_bitrate, bool initial, uint16_t reset_duration = 10, bool pulldown_rst_mode = false)
'''

lmarzen, 2023-09-18:
Maybe the data sheet can help shed some light?
https://www.waveshare.com/w/upload/6/60/7.5inch_e-Paper_V2_Specification.pdf

nglessner, 2023-09-18:
Page 18 matches up with what I remember from when I was knee deep into this
project. I would guess that a partial refresh is possible *without *a full
reset so long as the display is kept in deep sleep versus being turned
off.  I also never got so far as to test this though.
[image: image.png]

On Mon, Sep 18, 2023 at 8:51 AM Luke Marzen ***@***.***>
wrote:

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

lmarzen, 2023-09-18:
@nglessner Good find.

I think the solution may be to use `hibernate()` instead of `poweroff`

```C++
// turns powerOff() and sets controller to deep sleep for minimum power use, ONLY if wakeable by RST (rst >= 0)
    void hibernate()
```

lmarzen, 2023-09-18:
@nglessner Good find.

GxEPD2 provides a `hibernate()` function which may acheive this?
```C++
// turns powerOff() and sets controller to deep sleep for minimum power use, ONLY if wakeable by RST (rst >= 0)
    void hibernate()
```

nglessner, 2023-09-18:
I think the only way to know for sure is to test it. Finding (and trusting)
any documentation beyond the datasheet you linked above has been difficult.

On Mon, Sep 18, 2023 at 9:55 AM Luke Marzen ***@***.***>
wrote:

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

lmarzen, 2023-09-18:
You're right.

I did some more reading though, and found some insight from the author of the GxEPD2 driver library.
https://forum.arduino.cc/t/waveshare-e-paper-displays-with-spi/467865/1244?page=63

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

lmarzen, 2023-12-17:
Stale. Will reopen if discussion resumes.

ltwin8, 2024-08-18:
would it be possible to use the RTCs RAM or some other non volatile ram that remains powered when in sleep to store the current screen (not as pixels but information to build it) then if woken up just check where to does the screen need to change?

Closed 2023-12-17.

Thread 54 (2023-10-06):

75b_V2 display is not working

bob-u, 2023-10-06:
I have a no name tricolor display with waveshare ESP32 e-paper driver board that work with waveshare arduino examples, when 75b_v2 is selected.  It also works with ESPHome.  However esp32-weather-epd does nothing - screen does not flicker, and screen init / render portion happens very quickly which leads me to believe that this portion fails quietly (no errors in console)

I added print to console when initDisplay() and drawString() function is called, output below.  Any suggestions on  how to troubleshoot this issue?  I'm pretty sure that pin assignment is correct and as I mentioned earlier my setup works with other apps.

```
start=1696514055&end=1696600454&appid={API key}
  200 OK
Reading from BME280... BME not found
initDisplay
drawString
drawString
drawString
drawString
drawString
drawString
drawString
drawString
drawString
drawString
drawString
drawString
drawString
drawString
drawString
drawString
drawString
drawString
drawString
drawString
drawString
drawString
drawString
drawString
drawString
drawString
drawString
drawString
drawString
drawString
drawString
drawString
drawString
drawString
drawString
drawString
drawString
drawString
drawString
drawString
drawString
drawString
drawString
drawString
drawString
drawString
drawString
drawString
drawString
drawString
drawString
drawString
drawString
drawString
drawString
drawString
drawString
drawString
drawString
drawString
drawString
drawString
drawString
drawString
drawString
drawString
drawString
drawString
drawString
drawString
drawString
drawString
drawString
drawString
drawString
drawString
drawString
drawString
drawString
drawString
drawString
drawString
drawString
_PowerOn : 26
drawString
drawString
drawString
drawString
drawString
drawString
drawString
drawString
drawString
drawString
drawString
drawString
drawString
drawString
drawString
drawString
drawString
drawString
drawString
drawString
drawString
drawString
drawString
drawString
drawString
drawString
drawString
drawString
drawString
drawString
drawString
drawString
drawString
drawString
drawString
drawString
drawString
drawString
drawString
drawString
drawString
drawString
drawString
drawString
drawString
drawString
drawString
drawString
drawString
drawString
drawString
drawString
drawString
drawString
drawString
drawString
drawString
drawString
drawString
drawString
drawString
drawString
drawString
drawString
drawString
drawString
drawString
drawString
drawString
drawString
drawString
drawString
drawString
drawString
drawString
drawString
drawString
drawString
drawString
drawString
drawString
drawString
drawString
_Update_Full : 10
_PowerOff : 2
_PowerOff : 2
Awake for 12.064s
Deep-sleep for 352s
```

Here's EPD_7in5B_v2 init from waveshare demo:
```
int EPD_7in5B_V2_Init(void)
{
    EPD_Reset();

    EPD_SendCommand(0x01);			//POWER SETTING
    EPD_SendData(0x07);
    EPD_SendData(0x07);    //VGH=20V,VGL=-20V
    EPD_SendData(0x3f);		//VDH=15V
    EPD_SendData(0x3f);		//VDL=-15V

    EPD_SendCommand(0x04); //POWER ON
    delay(100);
    EPD_7in5_V2_Readbusy();

    EPD_SendCommand(0X00);			//PANNEL SETTING
    EPD_SendData(0x0F);   //KW-3f   KWR-2F	BWROTP 0f	BWOTP 1f

    EPD_SendCommand(0x61);        	//tres
    EPD_SendData(0x03);		//source 800
    EPD_SendData(0x20);
    EPD_SendData(0x01);		//gate 480
    EPD_SendData(0xE0);

    EPD_SendCommand(0X15);
    EPD_SendData(0x00);

    EPD_SendCommand(0X50);			//VCOM AND DATA INTERVAL SETTING
    EPD_SendData(0x11);
    EPD_SendData(0x07);

    EPD_SendCommand(0X60);			//TCON SETTING
    EPD_SendData(0x22);

    EPD_SendCommand(0x65);  // Resolution setting
    EPD_SendData(0x00);
    EPD_SendData(0x00);//800*480
    EPD_SendData(0x00);
    EPD_SendData(0x00);

    UWORD i;
    EPD_SendCommand(0x10);
    for(i=0; i<800 / 8 *480; i++) {
        EPD_SendData(0x00);

    }
    EPD_SendCommand(0x13);
    for(i=0; i<800 / 8 *480; i++)	{
        EPD_SendData(0x00);
    }

    EPD_SendCommand(0x10);
    return 0;
}

```

bob-u, 2023-10-07:
Had to swap SCK with MOSI and use hspi.  Great looking weather dashboard, thank you for making it.  What would make it even better would be a way to pull sensor data from HA.

torytyler, 2023-12-31:
I'm having the same issue with the E-Paper Driver ESP32 Board, the pinout is using hspi and not posting data to the e-paper display.

Is there any way you can provide the changes you made? This display is working with the waveshare arduino examples. So I know it's gotta be something simple, not a complete rewrite

Closed 2023-10-07.

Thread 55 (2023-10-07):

Failed to connect to ESP32

DaveTakesPictures, 2023-10-07:
I'm having trouble uploading the project. There is one warning early on, and though I just updated Python, it persists and I'm not sure if that's the cause anyway.

Second error, rather generic, I looked at the link, tried suggestions such as disconnecting everything and still can't upload. It's my first time using PIO and just guessing... shouldn't I have a USB connection? I see /dev/cu.Bluetooth-Incoming-Port but I'm not connected by bluetooth?? I'm on a mac running OS12.7 and VS 1.83.0

A fatal error occurred: Failed to connect to ESP32: No serial data received.
For troubleshooting steps visit: https://docs.espressif.com/projects/esptool/en/latest/troubleshooting.html
*** [upload] Error 2

Full terminal ouput below:

> ================================================== [FAILED] Took 92.01 seconds ==================================================

Environment                 Status    Duration
--------------------------  --------  ------------
dfrobot_firebeetle2_esp32e  FAILED    00:01:32.008
============================================= 1 failed, 0 succeeded in 00:01:32.008 =============================================

 *  The terminal process "platformio 'run', '--target', 'upload'" terminated with exit code: 1.
 *  Terminal will be reused by tasks, press any key to close it.

 *  Executing task in folder platformio: platformio run --target upload

/Users/davepixmb12/.platformio/penv/lib/python3.9/site-packages/urllib3/__init__.py:34: NotOpenSSLWarning: urllib3 v2.0 only supports OpenSSL 1.1.1+, currently the 'ssl' module is compiled with 'LibreSSL 2.8.3'. See: https://github.com/urllib3/urllib3/issues/3020
  warnings.warn(
Processing dfrobot_firebeetle2_esp32e (board: dfrobot_firebeetle2_esp32e; platform: espressif32 @ 6.4.0; framework: arduino)
----------------------------------------------------------------------------------------------------------------------------------
/Users/davepixmb12/.platformio/penv/lib/python3.9/site-packages/urllib3/__init__.py:34: NotOpenSSLWarning: urllib3 v2.0 only supports OpenSSL 1.1.1+, currently the 'ssl' module is compiled with 'LibreSSL 2.8.3'. See: https://github.com/urllib3/urllib3/issues/3020
  warnings.warn(
Verbose mode can be enabled via `-v, --verbose` option
CONFIGURATION: https://docs.platformio.org/page/boards/espressif32/dfrobot_firebeetle2_esp32e.html
PLATFORM: Espressif 32 (6.4.0) > DFRobot Firebeetle 2 ESP32-E
HARDWARE: ESP32 80MHz, 320KB RAM, 4MB Flash
DEBUG: Current (cmsis-dap) External (cmsis-dap, esp-bridge, esp-prog, iot-bus-jtag, jlink, minimodule, olimex-arm-usb-ocd, olimex-arm-usb-ocd-h, olimex-arm-usb-tiny-h, olimex-jtag-tiny, tumpa)
PACKAGES:
 - framework-arduinoespressif32 @ 3.20011.230801 (2.0.11)
 - tool-esptoolpy @ 1.40501.0 (4.5.1)
 - tool-mkfatfs @ 2.0.1
 - tool-mklittlefs @ 1.203.210628 (2.3)
 - tool-mkspiffs @ 2.230.0 (2.30)
 - toolchain-xtensa-esp32 @ 8.4.0+2021r2-patch5
LDF: Library Dependency Finder -> https://bit.ly/configure-pio-ldf
LDF Modes: Finder ~ chain, Compatibility ~ soft
Found 40 compatible libraries
Scanning dependencies...
Dependency Graph
|-- Adafruit BME280 Library @ 2.2.2
|-- Adafruit BusIO @ 1.14.4
|-- Adafruit Unified Sensor @ 1.1.13
|-- ArduinoJson @ 6.21.3
|-- GxEPD2 @ 1.5.2
|-- pollutant-concentration-to-aqi
|-- HTTPClient @ 2.0.0
|-- SPI @ 2.0.0
|-- WiFi @ 2.0.0
|-- WiFiClientSecure @ 2.0.0
|-- Preferences @ 2.0.0
|-- Wire @ 2.0.0
Building in release mode
Retrieving maximum program size .pio/build/dfrobot_firebeetle2_esp32e/firmware.elf
Checking size .pio/build/dfrobot_firebeetle2_esp32e/firmware.elf
Advanced Memory Usage is available via "PlatformIO Home > Project Inspect"
RAM:   [===       ]  31.0% (used 101744 bytes from 327680 bytes)
Flash: [====      ]  44.5% (used 1401097 bytes from 3145728 bytes)
Configuring upload protocol...
AVAILABLE: cmsis-dap, esp-bridge, esp-prog, espota, esptool, iot-bus-jtag, jlink, minimodule, olimex-arm-usb-ocd, olimex-arm-usb-ocd-h, olimex-arm-usb-tiny-h, olimex-jtag-tiny, tumpa
CURRENT: upload_protocol = esptool
Looking for upload port...
Auto-detected: /dev/cu.Bluetooth-Incoming-Port
Uploading .pio/build/dfrobot_firebeetle2_esp32e/firmware.bin
esptool.py v4.5.1
Serial port /dev/cu.Bluetooth-Incoming-Port
Connecting......................................

A fatal error occurred: Failed to connect to ESP32: No serial data received.
For troubleshooting steps visit: https://docs.espressif.com/projects/esptool/en/latest/troubleshooting.html
*** [upload] Error 2
================================================== [FAILED] Took 95.12 seconds ==================================================

Environment                 Status    Duration
--------------------------  --------  ------------
dfrobot_firebeetle2_esp32e  FAILED    00:01:35.118
============================================= 1 failed, 0 succeeded in 00:01:35.118 =============================================

 *  The terminal process "platformio 'run', '--target', 'upload'" terminated with exit code: 1.
 *  Terminal will be reused by tasks, press any key to close it.

lmarzen, 2023-10-08:
Try running  `ioreg -p IOUSB` which will list USB devices. This way you can see if it is being detected by the OS.

DaveTakesPictures, 2023-10-09:
Thanks Luke, I'll try and work on the Mac connection later, I wrangled a PC and was able to connect and upload successfully! Works like a charm! Thanks for the great project!

Closed 2023-10-20.

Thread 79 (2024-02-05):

Battery voltage read is wrong

FrAllard, 2024-02-05:
I recently enabled the option to display the battery voltage on the screen for the Firebeetle ESP32-E v1.0. My concern arose when the voltage reading was unexpectedly high, showing 4.40V, which surpasses the typical maximum charge level for a LiPo battery (4.2V). However, upon verification with a multimeter, the actual battery voltage was confirmed to be safely below 4.2V.

This led me to question the accuracy of the firmware's battery voltage reading. Incorrect voltage readings could potentially compromise the effectiveness of the battery's monitoring and protection systems, possibly failing to trigger the necessary protections due to an overestimated voltage reading.

To address this issue, I adjusted the conversion factor back to (3.3 / 2.0) in the setup function of the main.cpp file, contrary to the comments suggesting a different factor for the ESP32-E version. This adjustment, which leans towards underestimation, is a precautionary measure I prefer; it theoretically triggers protection mechanisms earlier, which is a safer approach for battery management.

It's worth noting that the Firebeetle seems to charge the battery correctly, so my concern about overcharging is minimal. However, this experience has highlighted that there may be variations in the Firebeetle ESP32-E boards concerning how battery voltage is read. This discrepancy is something users should be aware of, especially since it can affect the accuracy of displayed battery voltages and potentially impact battery protection logic.

lmarzen, 2024-02-05:
Thanks, for sharing your concern. I feared this may be the case. Maybe I should make this value adjustable via the config? I'll do some research first and see if there is a better way to go about this. Feel free to share any other suggestions you may have.

-Luke

lmarzen, 2024-02-05:
I'll have to experiment with this, but it seems like the esp32 may be precalibrated by the manufacturer,
https://docs.espressif.com/projects/esp-idf/en/v4.4/esp32/api-reference/peripherals/adc.html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

lmarzen, 2024-02-17:
Should be fixed now. Reopen this issue if you are still having issues.

Closed 2024-02-17.

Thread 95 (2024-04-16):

Washed out display after refresh

TheMeanCanEHdian, 2024-04-16:
Today I noticed a new problem where the display is washed out and splotchy over a certain vertical threshold. I was wondering if you had any thoughts on what might be causing this outside of a hardware issue. Below are an image showing the issue and a video showing the refresh process (after a reset).

The display looks sharp while refreshing, so I am not sure what might be the issue.

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

https://github.com/lmarzen/esp32-weather-epd/assets/16025103/c0df2252-cd29-479f-b8dc-800b93110626

TheMeanCanEHdian, 2024-04-16:
I also tried the following with no change:
- Reseating the display cables and connectors
- Removing and reconnecting the battery
- Powering with USB and battery connected
- Powering with only USB connected

lmarzen, 2024-04-16:
What driver board are you using (Waveshare Rev2.2/2.3 or DESPI-CO2)? Make sure the switch(es) are set as specified in the README.

TheMeanCanEHdian, 2024-04-16:
The switch was set as specified (when I move it to the other position it is way worse) but when I moved it back it now seems good? Perhaps the switch was slightly loose. It's all locked in my enclosure so not sure what would have happened but it's looking good!

Perhaps this will help someone in the future. Thanks!

lmarzen, 2024-04-16:
Interesting. Thanks for responding with your fix. I didn't even think that the switch might not be all the way set in position. This may help others with similar issues.

ayh20, 2024-11-24:
FWIW - I came here to find the link to buy a new panel as mine had become "faded" after working just fine for the last year or so.  Just thought i'd search the posts to see if anyone else had had any failures and saw this post.

Did the the same as OP. Flipped the Display config switch, reset and the screen is dark... flipped it back and reset, screen is displaying again correctly !

Hope this helps someone else

Closed 2024-04-16.

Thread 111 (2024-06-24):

Display not turning on

AmicableTarsier, 2024-06-24:
I walked through all of issue #81 and it still will not turn on. Here is the output from my serial monitor(masked lat and lon):

IP: 192.168.1.14
Waiting for SNTP synchronization......
Monday, June 24, 2024 19:04:32
Attempting HTTP request: api.openweathermap.org/data/3.0/onecall?lat=lat&lon=-lon&lang=en&units=standard&exclude=minutely&appid={API key}
  200 OK
Attempting HTTP request: api.openweathermap.org/data/2.5/air_pollution/history?lat=lat&lon=-lon&start=1719183876&end=1719270275&appid={API key}
  200 OK
Reading from BME280... BME not found
_PowerOn : 22
_Update_Full : 1001
_PowerOff : 2
Awake for 7.806s
Entering deep sleep for 1532s

Also not sure why the BME280 isn't working. I've unplugged and replugged everything, fixed the polarity of my battery and still nothing. Not sure what it could be.

lmarzen, 2024-06-24:
It appears to be a wiring issue or pin configuration issue. It's not detecting the display or bme.

Please let me know what model of esp32 and what model of driver board you are using.

I can confirm the correctness of your wiring if you provide a photo. Also, copy and paste your pin configuration from config.cpp.

AmicableTarsier, 2024-06-24:
Here are some photos of everything plugged in. I’ve realized having the same color wires is not ideal, but they’re what I’ve got
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

AmicableTarsier, 2024-06-24:
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

firebeetle esp32e

`// ADC pin used to measure battery voltage
const uint8_t PIN_BAT_ADC  = A2; // A0 for micro-usb firebeetle
// Pins for Waveshare e-paper Driver Board
const uint8_t PIN_EPD_BUSY = 14; // 5 for micro-usb firebeetle
const uint8_t PIN_EPD_CS   = 13;
const uint8_t PIN_EPD_RST  = 21;
const uint8_t PIN_EPD_DC   = 22;
const uint8_t PIN_EPD_SCK  = 18;
const uint8_t PIN_EPD_MISO = 19; // 19 Master-In Slave-Out not used, as no data from display
const uint8_t PIN_EPD_MOSI = 23;
const uint8_t PIN_EPD_PWR  = 26; // Irrelevant if directly connected to 3.3V
// I2C Pins used for BME280
const uint8_t PIN_BME_SDA = 17;
const uint8_t PIN_BME_SCL = 16;
const uint8_t PIN_BME_PWR =  4;   // Irrelevant if directly connected to 3.3V
const uint8_t BME_ADDRESS = 0x76; `

lmarzen, 2024-06-24:
The wires between your esp32 and despi look to be wired correctly. Try moving the switch on the despi from 0.47 to 3 and back, in the past some people have reported this fixed their issue saying that the switch wasn't all the way in position.

you can try changing the BME280 address to 0x77. If you can find the data sheet for your exact model it might tell you what address is correct.
```C
const uint8_t BME_ADDRESS = 0x77;
```

AmicableTarsier, 2024-06-24:
Tried those fixes and still nothing. I've reflashed multiple times(including now) and here's the output:

Reading from BME280... BME not found
Busy Timeout!
_PowerOn : 10001242
Busy Timeout!
_Update_Full : 10000135
Busy Timeout!
_PowerOff : 10000123
Awake for 39.577s
Entering deep sleep for 1174s

I've also tried it in the 3 position, switching back forth a few times, trying it with the 3.3v connected directly to 3.3v pinout and still nothing. Could the board be defective? This is my first time working with display screens like this.

Further(maybe dumb) question: Do I need to solder the pins? or will the through hole plugin via wire be enough? It seems to write to it no problem, but not sure if that's just good feelings about it or not

lmarzen, 2024-06-25:
I think your last question is the answer. Yes, you need to solder the pins to have proper electrical connections.

AmicableTarsier, 2024-06-25:
Well, I’ll do that in a bit and see if that solves all my issues.

AmicableTarsier, 2024-06-25:
Yup, solder was the problem! Thanks, that's good to know for the future

Closed 2024-06-25.

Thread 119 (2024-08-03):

E-Paper hat rev2.3

ltwin8, 2024-08-03:
I have read a bit about the support of the driver hardware, the people reporting issues with the rev2.3 hardware could try to "re-update" their driver hardware. the inductor (old 68uH new 10uH) seems not to be the issue but the MOSFET Q1 seems to be at fault here.

https://files.waveshare.com/upload/8/8e/E-Paper_Driver_HAT.pdf                               (2.3)
https://files.waveshare.com/upload/8/87/E-Paper-Driver-HAT-Schematic.pdf              (2.2)

The transistor Q1 is responsible for creating the driver voltages, those ones are buffered in a 4.7uF MLCC, during dithering this "reservoir" seems to run dry and the DCDC can not keep up "refilling" it

the setting of RSEL to 470mR should allow higher current (after all its the sense shunt) but the transistor Q1 has a way to high Rds_on (around 3R) compared to the old one (around 0.2R) so i recommend to solder a transistor of this type "SI1308EDL-T1-GE3" or simmilar.

important is the following:
Vds >= 30V
Vgs_th <= 2V
Rds_on <= 0.25R at 2.5V-3V Vgs
low total gate charge, less than 2.5nC

this transistor is likely the one build into the old board:
https://www.mouser.de/ProductDetail/Vishay-Semiconductors/SI1308EDL-T1-GE3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

if you search for alternaives filter the results at your supplier of choice with the above given values and there you go... to finish the decision open the datasheet, search pinout and compare to datasheet of SI1308EDL-T1-GE3 (available at the link above)

To those not very experienced with soldering or dont have rework equipment: the old MOSFETon the board can get destroyed, either remove its plastic with a nail clipper or simmilar, than heat the 3 pads simultaniously or put a blob of solder on each of the 3 pads and do round robin heating. to solder in the new one should be easy, tin the leads, put it with tweezers in place, shotrt heat to each pad should be sufficient for reflowing

to make the effort in reviving the "new and better (sure...)" driver hat (2.3) can have some advantage because it does after all provide a layer of additional ESD protection for the screen.

if helpful maybe add this guide to the readme, as i think this "hack" is not so difficult to perform

Asdf1qaz, 2024-08-06:
Good work on this mate but those links you posted for the transistor location on the board are not working. Would you be able to post a pic of them?

Also, for Imarzen, I found this "The new HAT 2.3 from Waveshare will consume zero current when PWR is not pulled high, AND all control and data lines are set floating, set INPUT. Call display.end(); after display.hibernate(); and before setting processor to deep sleep."

Not sure how much power the V2.3 hats take when idle normally (I will test when I get home), but this might be good to implement so you can power it down just like how the BME280 is done

jordiuoc, 2024-08-06:
Hi!

Thank you for this project. It's super!

I wanted to share a potential improvement for e-paper hat rev.2.3. If you change the function `_InitDisplay` in the file `GxEPD2_750_T7.cpp` to:

```cpp
void GxEPD2_750_T7::_InitDisplay()
{
  if (_hibernating) _reset();

  // POWER SETTING
  _writeCommand(0x01);
  _writeData(0x07);    // VDS_EN, VDG_EN
  _writeData(0x07);    // VGH=20V, VGL=-20V
  _writeData(0x3E);    // VDH=14V (experiment with 0x3E, 0x40)
  _writeData(0x3E);    // VDL=-14V (experiment with 0x3E, 0x40)

  // PANEL SETTING
  _writeCommand(0x00);
  _writeData(0x1F);    // KW: 3F, KWR: 2F, BWROTP: 0F, BWOTP: 1F

  // TRES SETTING
  _writeCommand(0x61);
  _writeData(WIDTH / 256);  // source 800
  _writeData(WIDTH % 256);
  _writeData(HEIGHT / 256); // gate 480
  _writeData(HEIGHT % 256);

  _writeCommand(0x15);
  _writeData(0x00);

  // VCOM AND DATA INTERVAL SETTING
  _writeCommand(0x50);
  _writeData(0x27);    // LUTKW, N2OCP: copy new to old (experiment with 0x27, 0x2A, 0x2B)
  _writeData(0x06);    // Experiment with 0x06, 0x08

  // TCON SETTING
  _writeCommand(0x60);
  _writeData(0x22);
}
```

I found that experimenting with the VCOM and Data Interval settings was necessary. This file is part of a library, so modifying it might be tricky.

Additionally, I am encountering an issue with refreshing. I can still see old data after refreshing with new data. This might be a problem in the `initDisplay` function in the `renderer.cpp` file. If I find a solution, I will let you know. Meanwhile, any advice is welcome.

Best regards,

ltwin8, 2024-08-09:
can you confirm/meassure if voltages stay in check during updating? eink is very sensitive to this because it relies on stati charge to move particels precisely

ZinggJM, 2024-08-11:
There is a modified version of the driver class for GDEY075T7 available on my branch work_in_progress:
https://github.com/ZinggJM/GxEPD2/blob/work_in_progress/src/gdey/GxEPD2_750_GDEY075T7.cpp

This version adds the Power Save (PWS) controller command to the initialization (line 342).
It solves an issue I have seen with dithered bitmaps.
Thank you for this report.

ltwin8, 2024-08-18:
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

why would you change this part of the library? the issue with rev2.3 hat hardware is the use of a bad spec'd mosfet

jordiuoc, 2024-08-19:
Hi!

You are absolutely right. I shouldn't touch the library. For now, I'm looking for the previous hardware version, although I haven't been able to find it in my area. Interisting video of applied science: https://www.youtube.com/watch?v=MsbiO8EAsGw

Just to let you know, I'm using this project to determine whether I should irrigate or not. Based on the humidity percentages of my field and the weather conditions, I decide if irrigation is needed. The use of these e-Ink screens has been extremely interesting to me, so I took advantage of your project. People have interesting hobbies, don't they? :-)

lmarzen, 2024-08-25:
Bumped zinggjm/GxEPD2 version 1.5.6 ->1.5.8 (or higher) which includes the mentioned fixes. (2567265d69843ad01c24204927f7dc18bc09e22d)

SyahfiraTasya, 2024-12-13:
i have tried with schematic

lmarzen, 2024-12-13:
@SyahfiraTasya Did that work for you?

lmarzen, 2025-01-06:
Closing since no response. Assuming zinggjm/GxEPD2 version 1.5.8 resolved the issue. Will reopen if otherwise indicated.

Closed 2025-01-06.

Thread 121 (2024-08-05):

Battery Voltage reading error

Asdf1qaz, 2024-08-05:
Hay mate. Got it all working and its great.

Just found something though, the battery voltage reading is off.
At the moment, my battery (when idle, between screen refreshes) is sitting at 4.151 volts.
During screen refreshes, it goes down to 4.137-4.14 volts.

On the screen it displays 4.28 volts. (not sure when that reading gets taken though)

This isn't an issue in itself, where it can be bad is when the battery gets low.
If the software is 0.1-0.15V off, that could mean that the battery could get down too 2.85V before the software turns off, possibly severely damaging the battery and shortening its life by quite a bit.

I couldn't find anywhere to calibrate the voltage, so for now, I have just raised the CRIT_LOW_BATTERY_VOLTAGE to 3.2V (and all the voltages above it).

My suggestion is to put a setting in the config.ccp where you calibrate the voltage?

lmarzen, 2024-08-05:
Great observation. The voltage is taken as soon as the esp32 wakes up, before the epaper refreshes.
Also, note that the display will stop refreshing once LOW_BATTERY_VOLTAGE (3.2v) is reached. Once CRIT is reached the esp32 will no longer wake up to check the battery voltage to see if it is okay to refresh again and a manual press of the reset button will be required once the battery is charged again.

I will consider adjusting these to be slightly more conservative.

Asdf1qaz, 2024-08-06:
So the hardware is still charging, even though the voltage is displaying 4.28V, which to me, means that the hardware is reading correctly.

So either:
1. The firebeetle firmware is passing the wrong voltage to the software (I will do some testing tomorrow when I get back home with a small script and hopefully rule this out)

2. Your software is not using the passed voltage correctly and adding an offset

3. Your software is working as intended (which seems most probable as there is no high voltage warning popping up) and an offset that is added after all the calcs and checks are done. Messing with the a calibration or adding an offset would not help in this case as it means it would be changing the correct voltage. Tomorrow, I will confirm this is the issue by connecting the battery input pins to a lab power supply to see if a high voltage warning is displayed when the battery input voltage goes over 4.2V

lmarzen, 2024-08-06:
I think the voltage is read correctly as is. The esp32 reads it from an ADC pin and uses the factory voltage calibration fuses to correctly calculate the corresponding voltage. I believe you are observing the voltage drop that occurs when the epaper screen is refreshing (which occurs after the voltage is measured).

Closed 2024-08-25.

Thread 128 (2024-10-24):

E-paper display power consumption

androot2, 2024-10-24:
Are you disconnecting EPD power supply by GPIO pin? Because after that, display need to be full refreshed right?
I have similiar project, after ESP32 deep sleep I refreshing only minutes part on display. But I can't disconnect power supply, because partial refresh won't work. EPD power consumption, even after display.hibernate(); (GxEPD2_BW library) is too big for battery operation ~0,5mA measured in VCC line to EPD. My display is smaller, WeAct Studio, 2.13. It could have lower power consumption according to data sheet. Do you have any idea how to solve that?

mgmomo, 2024-10-24:
Hi, it can be handled by an "ugly" trick.  I created a similar project and I am disconnection the power suply with a mos fet. But I connect drain and source with a 22k ohm resistor. In my project the current is reduced. I dont remember the total numbers but I think it are about 50 to 70 uA. With an 2800 mAh Accu, the system is available for about 3 to 4 weeks. The system is in deep sleep for 1 minute. Every 10 minutes a full refresh is required.

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

androot2, 2024-10-25:
Hello, thank you for answer. I found a solution on Internet. Weak pull-up on E-paper RESET pin. I added 220 k resistor to 3.3 V. Current consumption drops to data sheet value. I think it could help for others. now E-paper Vcc pin may be connected directly to 3.3 V.

patcher-ms, 2025-04-02:
@androot2 I also have a WeAct Studio display (4.2" B/W) and I'm seeing a >500uA current when the display is in deep sleep.

From your comment I understand that you are connecting all the display pins directly to the ESP32 pins except for `reset`, where you are using a 220k pull-up resistor to 3.3V. Is this correct? I just tried the same and for me it didn't reduce the power consumption.

androot2, 2025-04-03:
EPD RST is connected to ESP32 pin and added external pullup 100-220k (doesn't matter).
EPD Vcc directly to power supply.

patcher-ms, 2025-04-03:
Thank you for your reply! That sounds pretty much what I tried but I can give it another try later.

A difference is that I was connecting EPD VCC to the 3.3V pin of the ESP32. I can try to connect it straight to the power supply. https://github.com/WeActStudio/WeActStudio.EpaperModule/issues/12#issuecomment-1851962229 shows that using 5V instead of 3.3V makes a big difference. My 3.3V current is 10x what they’re reporting but it’s definitely worth a try

androot2, 2025-04-03:
I don't use any of WeAct Studio boards, so I don't know. I have bare ESP32 S3 chip and some other components to drive EPD properly. I prepared PCBs for ESP32S3 and ESP32C3 (single core, less power supply). EPD RST pull up is very important to proper go to deep sleep mode. If you don't have it, EPD is woke up immediatelly and current is >500 uA.

[weather2.pdf](https://github.com/user-attachments/files/19584014/weather2.pdf)

Schematic is prepared for WROOM modules, and bare chips C3 and S3 so don't be confused with so many ICs :)

patcher-ms, 2025-04-03:
Earlier I chatted with WeAct Studio and they told me to connect VCC of the EPD to a source > 3.3V. I tried it and the difference is measurable. I haven't had a chance to look into why.

The current consumption of both Xiao ESP32C3 and the 4.2" display with both on deep sleep changed from ~650uA when I connected VCC of the EPD to the 3V3 pin on the board to ~105uA when I connected the EPD VCC to the power supply.

Closed 2024-10-25.

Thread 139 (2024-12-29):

No display output

NathanKolbas, 2024-12-29:
My apologies if this is not the right place to put this.

I am running into an issue where I am getting no display output. I am using the FireBeetle 2 ESP32-E linked in the README and the Good Display 7.5in also linked in the README. I tried two ESP32s. The first one I soldered the wires directly to the ESP32 and the second one is attached via breadboard. I tested all the connections with a multimeter to make sure the wires were connected. I also tried to use the 3.3v rail. The switch on the DESPI-CO2 is set to 0.47 (tried flipping it a few times). Double checked that the display ribbon cable is connected to the DESPI-CO2 (I can see indents on the ribbon cable's copper).

Here are some photos:
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

I am using the latest version of the repo on the main branch ([c7b343d](https://github.com/lmarzen/esp32-weather-epd/commit/c7b343ddbea77a5acb12a5d2197948c79bec0e12)). The only thing changed was `config.cpp`  with the usual (I removed the API key as to not make unneeded calls as it should still update the display).

Here is the output from serial after pressing the reset button a few times (some output removed that is not needed):
```
Reconnecting to COM7     Connected!
............
_PowerOn : 26
Busy Timeout!
_Update_Full : 10001131
Busy Timeout!
_PowerOff : 10001115
Awake for 33.738s
Entering deep sleep for 878s

rst:0x1 (POWERON_RESET),boot:0x13 (SPI_FAST_FLASH_BOOT)
configsip: 0, SPIWP:0xee
clk_drv:0x00,q_drv:0x00,d_drv:0x00,cs0_drv:0x00,hd_drv:0x00,wp_drv:0x00
mode:DIO, clock div:2
load:0x3fff0030,len:1184
load:0x40078000,len:13232
load:0x40080400,len:3028
entry 0x400805e4
Battery voltage: 4258mv
_PowerOn : 25
Busy Timeout!
_Update_Full : 10001131
Busy Timeout!
_PowerOff : 10001115
Awake for 46.522s
Entering deep sleep for 827s

rst:0x1 (POWERON_RESET),boot:0x13 (SPI_FAST_FLASH_BOOT)
configsip: 0, SPIWP:0xee
clk_drv:0x00,q_drv:0x00,d_drv:0x00,cs0_drv:0x00,hd_drv:0x00,wp_drv:0x00
mode:DIO, clock div:2
load:0x3fff0030,len:1184
load:0x40078000,len:13232
load:0x40080400,len:3028
entry 0x400805e4
Battery voltage: 4128mv
_PowerOn : 26
Busy Timeout!
_Update_Full : 10001131

rst:0x1 (POWERON_RESET),boot:0x13 (SPI_FAST_FLASH_BOOT)
configsip: 0, SPIWP:0xee
clk_drv:0x00,q_drv:0x00,d_drv:0x00,cs0_drv:0x00,hd_drv:0x00,wp_drv:0x00
mode:DIO, clock div:2
load:0x3fff0030,len:1184
load:0x40078000,len:13232
load:0x40080400,len:3028
entry 0x400805e4
Battery voltage: 4284mv
_PowerOn : 26
Busy Timeout!
_Update_Full : 10000131
Busy Timeout!
_PowerOff : 10000115
Awake for 31.013s
Entering deep sleep for 724s

rst:0x5 (DEEPSLEEP_RESET),boot:0x13 (SPI_FAST_FLASH_BOOT)
configsip: 0, SPIWP:0xee
clk_drv:0x00,q_drv:0x00,d_drv:0x00,cs0_drv:0x00,hd_drv:0x00,wp_drv:0x00
mode:DIO, clock div:2
load:0x3fff0030,len:1184
load:0x40078000,len:13232
load:0x40080400,len:3028
entry 0x400805e4
Battery voltage: 4210mv
Busy Timeout!
_PowerOn : 10001191
Busy Timeout!
_Update_Full : 10001123
Busy Timeout!
_PowerOff : 10001115
Awake for 40.385s
Entering deep sleep for 1771s
Disconnected
```

Any suggestions on what I could do or anything that looks incorrect? Thank you for your time and help!

samlhouston, 2024-12-29:
Looking at you pictures, it looks like your display ribbon code is upside down. I made the same mistake.
Try flipping it. Best of luck.
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

NathanKolbas, 2024-12-29:
@samlhouston That was was my problem. Can't believe I missed that... Thank you so much!

Closed 2024-12-29.

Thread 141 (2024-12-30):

Waveshare 7.3inch 6-Color won't display

zombor, 2024-12-30:
I'm trying to get this project working with `Waveshare 7.3inch 6-Color E-Paper Display Module` but the display doesn't seem to come on. It seems to have the same HAT as `Waveshare 7.3in ACeP e-Paper (F)` so I figured it might work.

I changed `include/config.h`:

```
$ git diff include/config.h
diff --git a/platformio/include/config.h b/platformio/include/config.h
index 67eaa6c4..6ca85f1b 100644
--- a/platformio/include/config.h
+++ b/platformio/include/config.h
@@ -28,9 +28,9 @@
 //   DISP_7C_F  - 7.3in ACeP e-Paper (F)  800x480px  7-Color
 //   DISP_BW_V1 - 7.5in e-Paper (v1)      640x384px  Black/White
 // Uncomment the macro that identifies your physical panel.
-#define DISP_BW_V2
+// #define DISP_BW_V2
 // #define DISP_3C_B
-// #define DISP_7C_F
+#define DISP_7C_F
 // #define DISP_BW_V1

 // E-PAPER DRIVER BOARD
@@ -39,8 +39,8 @@
 // The Waveshare rev2.2 is no longer in production.
 // Users of the Waveshare rev2.3 have reported experiencing low contrast issues.
 // Uncomment the macro that identifies your driver board hardware.
-#define DRIVER_DESPI_C02
-// #define DRIVER_WAVESHARE
+// #define DRIVER_DESPI_C02
+#define DRIVER_WAVESHARE

 // 3 COLOR E-INK ACCENT COLOR
 // Defines the 3rd color to be used when a 3+ color display is selected.
```

and hooked up the wires like I've seen in the examples (but this could be wrong and my whole problem):

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

Console debug output:

```
rst:0x1 (POWERON_RESET),boot:0x13 (SPI_FAST_FLASH_BOOT)
configsip: 0, SPIWP:0xee
clk_drv:0x00,q_drv:0x00,d_drv:0x00,cs0_drv:0x00,hd_drv:0x00,wp_drv:0x00
mode:DIO, clock div:2
load:0x3fff0030,len:1184
load:0x40078000,len:13232
load:0x40080400,len:3028
entry 0x400805e4
Battery voltage: 4174mv
...
Reading from BME280... BME not found
_InitDisplay reset : 17
_PowerOn : 1
_refresh : 2938000
_PowerOff : 1
Awake for 11.303s
Entering deep sleep for 1844s
```

I'm trying to get this working without soldering first, is that possible? I'm just using the header pins that came with the board right now. This is my first project like this so apologies if I've done anything dumb!

lmarzen, 2024-12-30:
You need to solder the header pins to the esp32 board in order to make a good electrical connection.

zombor, 2024-12-31:
Thanks, after soldering the pins and moving the grey cable to the 3.3V pin, it works :)

Of course doesn't actually display 6 colors, but I might try and modify the code to do that later. My battery doesn't seem to charge from usb (charge light stays off even when usb plugged in, but I'll try and figure that out on my own.

Closed 2025-01-01.

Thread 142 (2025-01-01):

invalid header: 0xffffffff

zombor, 2025-01-01:
I'm having this problem after deep sleep wakeup, not sure what is causing it. I lowered the sleep time to more reliably reproduce. Sometimes it comes out of deep sleep fine, but it eventually gets stuck in this error loop. Some googling about it suggests that the error means there's no bootloader or partition table. But why would it work okay for a few times and then get stuck in the error loop?

```
...
Awake for 22.942s
Entering deep sleep for 74s
ets Jul 29 2019 12:21:46

rst:0x5 (DEEPSLEEP_RESET),boot:0x13 (SPI_FAST_FLASH_BOOT)
configsip: 0, SPIWP:0xee
clk_drv:0x00,q_drv:0x00,d_drv:0x00,cs0_drv:0x00,hd_drv:0x00,wp_drv:0x00
mode:DIO, clock div:2
load:0x3fff0030,len:1184
load:0x40078000,len:13232
load:0x40080400,len:3028
entry 0x400805e4
[debug] Heap Size       : 259016 B
[debug] Available Heap  : 232092 B
[debug] Min Free Heap   : 226708 B
[debug] Max Allocatable : 110580 B
[debug] ADC Cal eFuse Vref
Battery voltage: 4016mv
...
Waiting for SNTP synchronization.........
Wednesday, January 01, 2025 09:51:02
...
Reading from BME280... BME not found
_InitDisplay reset : 3996
_PowerOn : 173000
[debug] alerts.size()    : 0
[debug] alerts.size()    : 0
[debug] alerts.size()    : 0
[debug] alerts.size()    : 0
_refresh : 14499007
_PowerOff : 146000
[debug] Heap Size       : 256832 B
[debug] Available Heap  : 210492 B
[debug] Min Free Heap   : 105796 B
[debug] Max Allocatable : 110580 B
Awake for 22.625s
Entering deep sleep for 98s
ets Jul 29 2019 12:21:46

rst:0x5 (DEEPSLEEP_RESET),boot:0x13 (SPI_FAST_FLASH_BOOT)
invalid header: 0xffffffff
invalid header: 0xffffffff
invalid header: 0xffffffff
invalid header: 0xffffffff
invalid header: 0xffffffff
invalid header: 0xffffffff
invalid header: 0xffffffff
invalid header: 0xffffffff
invalid header: 0xffffffff
invalid header: 0xffffffff
invalid header: 0xffffffff
invalid header: 0xffffffff
invalid header: 0xffffffff
invalid header: 0xffffffff
ets Jul 29 2019 12:21:46

rst:0x7 (TG0WDT_SYS_RESET),boot:0x13 (SPI_FAST_FLASH_BOOT)
invalid header: 0xffffffff
invalid header: 0xffffffff
invalid header: 0xffffffff
invalid header: 0xffffffff
invalid header: 0xffffffff
invalid header: 0xffffffff
invalid header: 0xffffffff
invalid header: 0xffffffff
invalid header: 0xffffffff
invalid header: 0xffffffff
invalid header: 0xffffffff
invalid header: 0xffffffff
invalid header: 0xffffffff
invalid header: 0xffffffff
ets Jul 29 2019 12:21:46
```

Then it constantly prints the `rst:0x7 (TG0WDT_SYS_RESET),boot:0x13 (SPI_FAST_FLASH_BOOT)` stuff over and over again.

lmarzen, 2025-01-05:
I am talking to another user who is experiencing the same issue. Investigating..

lmarzen, 2025-01-05:
Try doing a clean build. Near the upload button first click 'Platformio: Clean', then upload again.
Let me know if that fixes it.

zombor, 2025-01-06:
Unfortunately not. I tried completely re-installing VS Code too just to make sure there was nothing laying around.

lmarzen, 2025-01-06:
The other user who recently reported the same issue, tried swapping their board out for another and made no other changes, and it resolved their issue.

I suspect it is a corrupted bootloader.

Someone had a similar issue and they claimed reflashing the bootloader fixed the issue.
https://github.com/sle118/squeezelite-esp32/discussions/271#discussioncomment-6481776
They link to this forum post with instructions:
https://forums.slimdevices.com/forum/user-forums/3rd-party-hardware/109412-announce-squeezelite-esp32-dedicated-thread/page119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

Closed 2025-01-06.

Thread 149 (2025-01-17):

Poor/no display, busy timeout with GDEY075Z08 3-color display

lipusal, 2025-01-17:
Hello! First of all, thank you very much for putting this code together, as well as for your extensive help with similar open issues, it's clear you care about folks getting their stuff to work. I'm hoping you'll be able to help me out too; I've put together hardware and software as guided in the repository, but my display is either not displaying at all, or displaying very faintly and/or flickering. Similar issues have pointed out to configuration issues or power, but before getting new hardware components or re-soldering I'd like to make sure I've done everything else I can.  Here's my setup:

### Hardware
- Board: FireBeetle 2 ESP32-E
- Display: Good Display GDEY075Z08 (3-color)
- Adapter: DESPI-C02 (RESE switch set to 0.47)
- No battery connected yet
- No BME connected yet

<details>
  <summary>Photos</summary>

#### Dim display + border box
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

</details>

### Configuration
I forked this to set my own config, the differences are [here](https://github.com/lmarzen/esp32-weather-epd/compare/main...lipusal:esp32-weather-epd:main).

## Symptoms
- Display will not turn on at all. Console shows `Busy timeout`
- Display shows a thick black border around
- Switching the DESPI switch to 3 and back to 0.47 caused one initial render once, but display remained faint after

### Console output
<details>
  <summary>Click to expand</summary>

```
Hard resetting via RTS pin...
--- Terminal on COM4 | 115200 8-N-1
--- Available filters and text transformations: colorize, debug, default, direct, esp32_exception_decoder, hexlify, log2file, nocontrol, printable, send_on_enter, time
--- More details at https://bit.ly/pio-monitor-filters
--- Quit: Ctrl+C | Menu: Ctrl+T | Help: Ctrl+T followed by Ctrl+H
ets Jul 29 2019 12:21:46

rst:0x1 (POWERON_RESET),boot:0x13 (SPI_FAST_FLASH_BOOT)
configsip: 0, SPIWP:0xee
clk_drv:0x00,q_drv:0x00,d_drv:0x00,cs0_drv:0x00,hd_drv:0x00,wp_drv:0x00
mode:DIO, clock div:2
load:0x3fff0030,len:1184
load:0x40078000,len:13232
load:0x40080400,len:3028
entry 0x400805e4
Connecting to 'xxxxxxxxxx'...
IP: 10.42.55.107
Waiting for SNTP synchronization..............................................
Thursday, January 16, 2025 21:30:51
Attempting HTTP request: api.openweathermap.org/data/3.0/onecall?lat=37.520&lon=-122.276&lang=en&units=standard&exclude=minutely&appid={API key}
  200 OK
Attempting HTTP request: api.openweathermap.org/data/2.5/air_pollution/history?lat=37.520&lon=-122.276&start=1737005455&end=1737091854&appid={API key}
  200 OK
Reading from BME280... BME not found
Busy Timeout!
_PowerOn : 20001265
Busy Timeout!
_Update_Full : 20001269
Busy Timeout!
_PowerOff : 20001107
Busy Timeout!
_PowerOff : 20001107
Awake for 92.077s
Entering deep sleep for 1667s
```
</details>

## Possible workaround
Connecting the display's 3.3v directly to the FireBeetle's makes the display vivid but flickery, similar to #123 (root cause there was an unsupported display; mine is supposedly supported). After a while, the display seems to stabilize. **Is this the expected behavior?** Please see [video](https://youtu.be/C3hYHiITJtE) (the display starts in its dim state and I press the reset button in the beginning)

<details>
  <summary>Console output during the video linked above</summary>

```
rst:0x1 (POWERON_RESET),boot:0x13 (SPI_FAST_FLASH_BOOT)
configsip: 0, SPIWP:0xee
clk_drv:0x00,q_drv:0x00,d_drv:0x00,cs0_drv:0x00,hd_drv:0x00,wp_drv:0x00
mode:DIO, clock div:2
load:0x3fff0030,len:1184
load:0x40078000,len:13232
load:0x40080400,len:3028
entry 0x400805e4
Connecting to 'xxxxxxxxxx'....
IP: 10.42.55.107
Waiting for SNTP synchronization..................
Thursday, January 16, 2025 22:06:25
Attempting HTTP request: api.openweathermap.org/data/3.0/onecall?lat=37.520&lon=-122.276&lang=en&units=standard&exclude=minutely&appid={API key}
  200 OK
Attempting HTTP request: api.openweathermap.org/data/2.5/air_pollution/history?lat=37.520&lon=-122.276&start=1737007589&end=1737093988&appid={API key}
  200 OK
Reading from BME280... BME not found
_PowerOn : 128993
Busy Timeout!
_Update_Full : 20001267
_PowerOff : 6051001
_PowerOff : 41001
Awake for 35.522s
Entering deep sleep for 1387s
```
</details>

----

Should I just leave the display connected directly to 3.3v? Anything else that I might've missed or misconfigured? Thanks in advance for your help 🙏

lmarzen, 2025-01-17:
Thanks for the kind words, but also for providing a detailed description of the troubleshooting steps you've taken.

The flickering is part of the expected refresh sequence of epaper displays. The more colors the epaper panel supports the more flickery the refresh. The black and white display refreshes in 4 seconds, whereas the 3 color you have is expected to take around 26 seconds. The 7-color panels take around 35s.

With regards to directly connecting to 3.3v, yes please do that. Others have experienced similar issues recently and this is the solution, I have been busy lately, but I have been meaning to update the wiring diagrams to indicate this. The original idea was to increase power savings by running the display off the power of a GPIO pin, which has enough power to be able to drive the black and white display, but as I have found out recently not the multi color displays. I will revert the wiring back to using 3.3v for powering the epaper in the coming days/week when I find time.

Let me know if you have any other questions.

lipusal, 2025-01-17:
Thanks for the quick and detailed response! That makes things easier then, will close this as resolved for now. I will keep an eye out for updates in case a solution is found to achieve the same power savings off of a GPIO port. In any case, thank you =)

itopaloglu83, 2025-01-31:
Very informative and well documented issue. Thank you.

For anyone checking this later, it looks like the [GxEPD2](https://github.com/ZinggJM/GxEPD2) library doesn't directly support the display part number GDEY075Z08. The supported panels list doesn't contain the part number and also the library owner made a comment (https://github.com/ZinggJM/GxEPD2/pull/61#issuecomment-1868896192) saying he doesn't have that display.

I wish I had known the amount of flicker 3 colored displays have. I would've bought the black-and-white one instead.

whtech, 2025-03-19:
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

GxEPD2 does support GDEY075Z08 3 colors. I tried it on FireBeetle 2 ESP32-E and ESP32 c3 dev boards. both of them worked.

Closed 2025-01-17.

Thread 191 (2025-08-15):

BMP 280 not found when powered from Firebeetle Digital Output D12

bgalport, 2025-08-15:
The BME280 sensor is not detected when VIN is connected to the Firebeetle IO 4 (D12), but is detected if VIN is connected to 3.3v.
When connected to IO4 I can see on an Oscilloscope that the pin goes high for approx 2.3ms during an update.
Is this a know issue or a timing problem with my sensor?

bgalport, 2025-08-15:
Should have done more research before posting. Others have resolved the issue by adding a short 300mS delay after the output is set high to allow the BME280 to stabilize before reading.

Closed 2025-08-15.

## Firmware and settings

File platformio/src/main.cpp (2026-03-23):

/* Main program for esp32-weather-epd.
 * Copyright (C) 2022-2026  Luke Marzen
 *
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
 * You should have received a copy of the GNU General Public License
 * along with this program.  If not, see <https://www.gnu.org/licenses/>.
 */

#include "config.h"
#include <Arduino.h>
#include <Adafruit_Sensor.h>
#include <Preferences.h>
#include <time.h>
#include <WiFi.h>
#include <Wire.h>

#include "_locale.h"
#include "api_response.h"
#include "client_utils.h"
#include "config.h"
#include "display_utils.h"
#include "icons/icons_196x196.h"
#include "renderer.h"

#if defined(SENSOR_BME280)
  #include <Adafruit_BME280.h>
#endif
#if defined(SENSOR_BME680)
  #include <Adafruit_BME680.h>
#endif
#if defined(USE_HTTPS_WITH_CERT_VERIF) || defined(USE_HTTPS_WITH_CERT_VERIF)
  #include <WiFiClientSecure.h>
#endif
#ifdef USE_HTTPS_WITH_CERT_VERIF
  #include "cert.h"
#endif

// too large to allocate locally on stack
static owm_resp_onecall_t       owm_onecall;
static owm_resp_air_pollution_t owm_air_pollution;

Preferences prefs;

/* Put esp32 into ultra low-power deep sleep (<11μA).
 * Aligns wake time to the minute. Sleep times defined in config.cpp.
 */
void beginDeepSleep(unsigned long startTime, tm *timeInfo)
{
  if (!getLocalTime(timeInfo))
  {
    Serial.println(TXT_REFERENCING_OLDER_TIME_NOTICE);
  }

  // To simplify sleep time calculations, the current time stored by timeInfo
  // will be converted to time relative to the WAKE_TIME. This way if a
  // SLEEP_DURATION is not a multiple of 60 minutes it can be more trivially,
  // aligned and it can easily be deterimined whether we must sleep for
  // additional time due to bedtime.
  // i.e. when curHour == 0, then timeInfo->tm_hour == WAKE_TIME
  int bedtimeHour = INT_MAX;
  if (BED_TIME != WAKE_TIME)
  {
    bedtimeHour = (BED_TIME - WAKE_TIME + 24) % 24;
  }

  // time is relative to wake time
  int curHour = (timeInfo->tm_hour - WAKE_TIME + 24) % 24;
  const int curMinute = curHour * 60 + timeInfo->tm_min;
  const int curSecond = curHour * 3600
                      + timeInfo->tm_min * 60
                      + timeInfo->tm_sec;
  const int desiredSleepSeconds = SLEEP_DURATION * 60;
  const int offsetMinutes = curMinute % SLEEP_DURATION;
  const int offsetSeconds = curSecond % desiredSleepSeconds;

  // align wake time to nearest multiple of SLEEP_DURATION
  int sleepMinutes = SLEEP_DURATION - offsetMinutes;
  if (desiredSleepSeconds - offsetSeconds < 120
   || offsetSeconds / (float)desiredSleepSeconds > 0.95f)
  { // if we have a sleep time less than 2 minutes OR less 5% SLEEP_DURATION,
    // skip to next alignment
    sleepMinutes += SLEEP_DURATION;
  }

  // estimated wake time, if this falls in a sleep period then sleepDuration
  // must be adjusted
  const int predictedWakeHour = ((curMinute + sleepMinutes) / 60) % 24;

  uint64_t sleepDuration;
  if (predictedWakeHour < bedtimeHour)
  {
    sleepDuration = sleepMinutes * 60 - timeInfo->tm_sec;
  }
  else
  {
    const int hoursUntilWake = 24 - curHour;
    sleepDuration = hoursUntilWake * 3600ULL
                    - (timeInfo->tm_min * 60ULL + timeInfo->tm_sec);
  }

  // add extra delay to compensate for esp32's with fast RTCs.
  sleepDuration += 3ULL;
  sleepDuration *= 1.0015f;

#if DEBUG_LEVEL >= 1
  printHeapUsage();
#endif

  esp_sleep_enable_timer_wakeup(sleepDuration * 1000000ULL);
  Serial.print(TXT_AWAKE_FOR);
  Serial.println(" "  + String((millis() - startTime) / 1000.0, 3) + "s");
  Serial.print(TXT_ENTERING_DEEP_SLEEP_FOR);
  Serial.println(" " + String(sleepDuration) + "s");
  esp_deep_sleep_start();
} // end beginDeepSleep

/* Program entry point.
 */
void setup()
{
  unsigned long startTime = millis();
  Serial.begin(115200);

#if DEBUG_LEVEL >= 1
  printHeapUsage();
#endif

  disableBuiltinLED();

  // Open namespace for read/write to non-volatile storage
  prefs.begin(NVS_NAMESPACE, false);

#if BATTERY_MONITORING
  uint32_t batteryVoltage = readBatteryVoltage();
  Serial.print(TXT_BATTERY_VOLTAGE);
  Serial.println(": " + String(batteryVoltage) + "mv");

  // When the battery is low, the display should be updated to reflect that, but
  // only the first time we detect low voltage. The next time the display will
  // refresh is when voltage is no longer low. To keep track of that we will
  // make use of non-volatile storage.
  bool lowBat = prefs.getBool("lowBat", false);

  // low battery, deep sleep now
  if (batteryVoltage <= LOW_BATTERY_VOLTAGE)
  {
    if (lowBat == false)
    { // battery is now low for the first time
      prefs.putBool("lowBat", true);
      prefs.end();
      initDisplay();
      do
      {
        drawError(battery_alert_0deg_196x196, TXT_LOW_BATTERY);
      } while (display.nextPage());
      powerOffDisplay();
    }

    if (batteryVoltage <= CRIT_LOW_BATTERY_VOLTAGE)
    { // critically low battery
      // don't set esp_sleep_enable_timer_wakeup();
      // We won't wake up again until someone manually presses the RST button.
      Serial.println(TXT_CRIT_LOW_BATTERY_VOLTAGE);
      Serial.println(TXT_HIBERNATING_INDEFINITELY_NOTICE);
    }
    else if (batteryVoltage <= VERY_LOW_BATTERY_VOLTAGE)
    { // very low battery
      esp_sleep_enable_timer_wakeup(VERY_LOW_BATTERY_SLEEP_INTERVAL
                                    * 60ULL * 1000000ULL);
      Serial.println(TXT_VERY_LOW_BATTERY_VOLTAGE);
      Serial.print(TXT_ENTERING_DEEP_SLEEP_FOR);
      Serial.println(" " + String(VERY_LOW_BATTERY_SLEEP_INTERVAL) + "min");
    }
    else
    { // low battery
      esp_sleep_enable_timer_wakeup(LOW_BATTERY_SLEEP_INTERVAL
                                    * 60ULL * 1000000ULL);
      Serial.println(TXT_LOW_BATTERY_VOLTAGE);
      Serial.print(TXT_ENTERING_DEEP_SLEEP_FOR);
      Serial.println(" " + String(LOW_BATTERY_SLEEP_INTERVAL) + "min");
    }
    esp_deep_sleep_start();
  }
  // battery is no longer low, reset variable in non-volatile storage
  if (lowBat == true)
  {
    prefs.putBool("lowBat", false);
  }
#else
  uint32_t batteryVoltage = UINT32_MAX;
#endif

  // All data should have been loaded from NVS. Close filesystem.
  prefs.end();

  String statusStr = {};
  String tmpStr = {};
  tm timeInfo = {};

  // START WIFI
  int wifiRSSI = 0; // “Received Signal Strength Indicator"
  wl_status_t wifiStatus = startWiFi(wifiRSSI);
  if (wifiStatus != WL_CONNECTED)
  { // WiFi Connection Failed
    killWiFi();
    initDisplay();
    if (wifiStatus == WL_NO_SSID_AVAIL)
    {
      Serial.println(TXT_NETWORK_NOT_AVAILABLE);
      do
      {
        drawError(wifi_x_196x196, TXT_NETWORK_NOT_AVAILABLE);
      } while (display.nextPage());
    }
    else
    {
      Serial.println(TXT_WIFI_CONNECTION_FAILED);
      do
      {
        drawError(wifi_x_196x196, TXT_WIFI_CONNECTION_FAILED);
      } while (display.nextPage());
    }
    powerOffDisplay();
    beginDeepSleep(startTime, &timeInfo);
  }

  // TIME SYNCHRONIZATION
  configTzTime(TIMEZONE, NTP_SERVER_1, NTP_SERVER_2);
  bool timeConfigured = waitForSNTPSync(&timeInfo);
  if (!timeConfigured)
  {
    Serial.println(TXT_TIME_SYNCHRONIZATION_FAILED);
    killWiFi();
    initDisplay();
    do
    {
      drawError(wi_time_4_196x196, TXT_TIME_SYNCHRONIZATION_FAILED);
    } while (display.nextPage());
    powerOffDisplay();
    beginDeepSleep(startTime, &timeInfo);
  }

  // MAKE API REQUESTS
#ifdef USE_HTTP
  WiFiClient client;
#elif defined(USE_HTTPS_NO_CERT_VERIF)
  WiFiClientSecure client;
  client.setInsecure();
#elif defined(USE_HTTPS_WITH_CERT_VERIF)
  WiFiClientSecure client;
  client.setCACert(cert_Sectigo_Public_Server_Authentication_Root_R46);
#endif
  int rxStatus = getOWMonecall(client, owm_onecall);
  if (rxStatus != HTTP_CODE_OK)
  {
    killWiFi();
    statusStr = "One Call " + OWM_ONECALL_VERSION + " API";
    tmpStr = String(rxStatus, DEC) + ": " + getHttpResponsePhrase(rxStatus);
    initDisplay();
    do
    {
      drawError(wi_cloud_down_196x196, statusStr, tmpStr);
    } while (display.nextPage());
    powerOffDisplay();
    beginDeepSleep(startTime, &timeInfo);
  }
  rxStatus = getOWMairpollution(client, owm_air_pollution);
  if (rxStatus != HTTP_CODE_OK)
  {
    killWiFi();
    statusStr = "Air Pollution API";
    tmpStr = String(rxStatus, DEC) + ": " + getHttpResponsePhrase(rxStatus);
    initDisplay();
    do
    {
      drawError(wi_cloud_down_196x196, statusStr, tmpStr);
    } while (display.nextPage());
    powerOffDisplay();
    beginDeepSleep(startTime, &timeInfo);
  }
  killWiFi(); // WiFi no longer needed

  // GET INDOOR TEMPERATURE AND HUMIDITY, start BMEx80...
  pinMode(PIN_BME_PWR, OUTPUT);
  digitalWrite(PIN_BME_PWR, HIGH);
#if defined(SENSOR_INIT_DELAY_MS) && SENSOR_INIT_DELAY_MS > 0
  delay(SENSOR_INIT_DELAY_MS);
#endif
  TwoWire I2C_bme = TwoWire(0);
  I2C_bme.begin(PIN_BME_SDA, PIN_BME_SCL, 100000); // 100kHz
  float inTemp     = NAN;
  float inHumidity = NAN;
#if defined(SENSOR_BME280)
  Serial.print(String(TXT_READING_FROM) + " BME280... ");
  Adafruit_BME280 bme;

  if(bme.begin(BME_ADDRESS, &I2C_bme))
  {
#endif
#if defined(SENSOR_BME680)
  Serial.print(String(TXT_READING_FROM) + " BME680... ");
  Adafruit_BME680 bme(&I2C_bme);

  if(bme.begin(BME_ADDRESS))
  {
#endif
    inTemp     = bme.readTemperature(); // Celsius
    inHumidity = bme.readHumidity();    // %

    // check if BME readings are valid
    // note: readings are checked again before drawing to screen. If a reading
    //       is not a number (NAN) then an error occurred, a dash '-' will be
    //       displayed.
    if (std::isnan(inTemp) || std::isnan(inHumidity))
    {
      statusStr = "BME " + String(TXT_READ_FAILED);
      Serial.println(statusStr);
    }
    else
    {
      Serial.println(TXT_SUCCESS);
    }
  }
  else
  {
    statusStr = "BME " + String(TXT_NOT_FOUND); // check wiring
    Serial.println(statusStr);
  }
  digitalWrite(PIN_BME_PWR, LOW);

  String refreshTimeStr;
  getRefreshTimeStr(refreshTimeStr, timeConfigured, &timeInfo);
  String dateStr;
  getDateStr(dateStr, &timeInfo);

  // RENDER FULL REFRESH
  initDisplay();
  do
  {
    drawCurrentConditions(owm_onecall.current, owm_onecall.daily[0],
                          owm_air_pollution, inTemp, inHumidity);
    drawOutlookGraph(owm_onecall.hourly, owm_onecall.daily, timeInfo);
    drawForecast(owm_onecall.daily, timeInfo);
    drawLocationDate(CITY_STRING, dateStr);
#if DISPLAY_ALERTS
    drawAlerts(owm_onecall.alerts, CITY_STRING, dateStr);
#endif
    drawStatusBar(statusStr, refreshTimeStr, wifiRSSI, batteryVoltage);
  } while (display.nextPage());
  powerOffDisplay();

  // DEEP SLEEP
  beginDeepSleep(startTime, &timeInfo);
} // end setup

/* This will never run
 */
void loop()
{
} // end loop

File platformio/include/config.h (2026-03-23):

/* Configuration option declarations for esp32-weather-epd.
 * Copyright (C) 2022-2026  Luke Marzen
 *
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
 * You should have received a copy of the GNU General Public License
 * along with this program.  If not, see <https://www.gnu.org/licenses/>.
 */

#ifndef __CONFIG_H__
#define __CONFIG_H__

#include <cstdint>
#include <Arduino.h>

// E-PAPER PANEL
// This project supports the following E-Paper panels:
//   DISP_BW_V2 - 7.5in e-Paper (v2)      800x480px  Black/White
//   DISP_3C_B  - 7.5in e-Paper (B)       800x480px  Red/Black/White
//   DISP_7C_F  - 7.3in ACeP e-Paper (F)  800x480px  7-Color
//   DISP_BW_V1 - 7.5in e-Paper (v1)      640x384px  Black/White
// Uncomment the macro that identifies your physical panel.
#define DISP_BW_V2
// #define DISP_3C_B
// #define DISP_7C_F
// #define DISP_BW_V1

// E-PAPER DRIVER BOARD
// The DESPI-C02 is the only officially supported driver board.
// Support for the Waveshare rev2.2 and rev2.3 is deprecated.
// The Waveshare rev2.2 is no longer in production.
// Users of the Waveshare rev2.3 have reported experiencing low contrast issues.
// Uncomment the macro that identifies your driver board hardware.
#define DRIVER_DESPI_C02
// #define DRIVER_WAVESHARE

// INDOOR ENVIRONMENT SENSOR
// Uncomment the macro that identifies your sensor.
#define SENSOR_BME280
// #define SENSOR_BME680

// If you encounter issues with the BME280 sensor showing no data, uncomment and
// add a small delay before reading it's value. 300ms seems to work for most people
// #define SENSOR_INIT_DELAY_MS 300

// 3 COLOR E-INK ACCENT COLOR
// Defines the 3rd color to be used when a 3+ color display is selected.
#if defined(DISP_3C_B) || defined(DISP_7C_F)
  // #define ACCENT_COLOR GxEPD_BLACK
  #define ACCENT_COLOR GxEPD_RED
  // #define ACCENT_COLOR GxEPD_GREEN
  // #define ACCENT_COLOR GxEPD_BLUE
  // #define ACCENT_COLOR GxEPD_YELLOW
  // #define ACCENT_COLOR GxEPD_ORANGE
#endif

// LOCALE
// If your locale is not here, you can add it by copying and modifying one of
// the files in src/locales. Please feel free to create a pull request to add
// official support for your locale.
//   Language (Territory)            code
//   German (Germany)                de_DE
//   English (United Kingdom)        en_GB
//   English (United States)         en_US
//   Estonian (Estonia)              et_EE
//   Finnish (Finland)               fi_FI
//   French (France)                 fr_FR
//   Italiano (Italia)               it_IT
//   Dutch (Belgium)                 nl_BE
//   Portuguese (Brazil)             pt_BR
//   Spanish (Spain)                 es_ES
#define LOCALE en_US

// UNITS
// Define exactly one macro for each measurement type below.

// UNITS - TEMPERATURE
//   Metric   : Celsius
//   Imperial : Fahrenheit
// #define UNITS_TEMP_KELVIN
// #define UNITS_TEMP_CELSIUS
#define UNITS_TEMP_FAHRENHEIT

// UNITS - WIND SPEED
//   Metric   : Kilometers per Hour
//   Imperial : Miles per Hour
// #define UNITS_SPEED_METERSPERSECOND
// #define UNITS_SPEED_FEETPERSECOND
// #define UNITS_SPEED_KILOMETERSPERHOUR
#define UNITS_SPEED_MILESPERHOUR
// #define UNITS_SPEED_KNOTS
// #define UNITS_SPEED_BEAUFORT

// UNITS - PRESSURE
//   Metric   : Millibars
//   Imperial : Inches of Mercury
// #define UNITS_PRES_HECTOPASCALS
// #define UNITS_PRES_PASCALS
// #define UNITS_PRES_MILLIMETERSOFMERCURY
#define UNITS_PRES_INCHESOFMERCURY
// #define UNITS_PRES_MILLIBARS
// #define UNITS_PRES_ATMOSPHERES
// #define UNITS_PRES_GRAMSPERSQUARECENTIMETER
// #define UNITS_PRES_POUNDSPERSQUAREINCH

// UNITS - VISIBILITY DISTANCE
//   Metric   : Kilometers
//   Imperial : Miles
// #define UNITS_DIST_KILOMETERS
#define UNITS_DIST_MILES

// UNITS - PRECIPITATION (HOURLY)
// Measure of precipitation.
// This can either be Probability of Precipitation (PoP) or hourly volume.
//   Metric   : Millimeters
//   Imperial : Inches
#define UNITS_HOURLY_PRECIP_POP
// #define UNITS_HOURLY_PRECIP_MILLIMETERS
// #define UNITS_HOURLY_PRECIP_CENTIMETERS
// #define UNITS_HOURLY_PRECIP_INCHES

// UNITS - PRECIPITATION (DAILY)
// Measure of precipitation.
// This can either be Probability of Precipitation (PoP) or daily volume.
//   Metric   : Millimeters
//   Imperial : Inches
// #define UNITS_DAILY_PRECIP_POP
// #define UNITS_DAILY_PRECIP_MILLIMETERS
// #define UNITS_DAILY_PRECIP_CENTIMETERS
#define UNITS_DAILY_PRECIP_INCHES
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

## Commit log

2022-03-08 created arduino sketch
2022-05-23 Completed screen sketch, added new icons, fixed bug with icon generation
    [main.cpp]
2022-05-29 Script to generate fonts with remapped degree symbol and a limited character set for large temperature display
2022-05-29 Fixed naming issue with ttf_to_adafruit_gfx.sh
    [main.cpp]
2022-06-05 Fixed spacing issue with drawString(), Added icons for current weather data
    [main.cpp]
2022-07-07 Reduced onecall request size by removing some unused data. Made onecall and air pollution structs static to prevent stack overflow
    [api_response.h, display_utils.cpp, main.cpp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]
2022-07-10 Fixed icon rotation, Added script to generate rotated icons, added secondary and tertiary intercardinal compass directions
    [config.h, display_utils.cpp, main.cpp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]
2022-07-10 added imperial units for pressure
2022-07-10 added to current conditions
2022-07-11 switched aqi to united states aqi
2022-07-11 fixed pressure calculation bug
    [renderer.cpp]
2022-07-12 switched temp/humidity sensor to bme280
2022-07-12 fixed font size bug
    [renderer.cpp]
2022-07-14 cleaned up debug prints
2022-07-16 add rotated battery icons and updated wind icon script
2022-07-16 added battery life calculations
2022-07-17 Added x axis to outlook graph
2022-07-18 added y axis to outlook graph
2022-07-18 Updated error message for wifi
    [main.cpp, renderer.cpp]
2022-07-18 reduced outlook graph buffer room for temperature
2022-07-19 Fixed bug with max hourly lookout graph
    [renderer.cpp]
2022-07-19 Added wiring section
2022-07-24 Alerts for heat now show thermometer icon
2022-10-26 fixed Day-Haze icon displaying during night time
    [display_utils.cpp]
2022-12-20 fix for Error redrerer.cpp #2
    [renderer.cpp]
2023-01-17 fix for esp32-e upload issue #3
2023-01-17 improved battery life calculations for esp32-e
2023-01-18 fixed memory issue caused by deleting alerts
    [display_utils.cpp, renderer.cpp]
2023-01-26 Improved API error messages
    [client_utils.cpp, main.cpp]
2023-01-29 removed debug print
2023-01-29 Work around for arduino String bug w/ 1 digit floats
    [renderer.cpp]
2023-01-31 Fixed graph bounds for -temps, % is remainder, not modulo
    [renderer.cpp]
2023-01-31 Added full screen error message for low battery
    [main.cpp, renderer.cpp, renderer.h]
2023-01-31 Added error screens for WiFi and Time
    [main.cpp, renderer.cpp, renderer.h]
2023-01-31 Added error screens for API connections
    [display_utils.cpp, main.cpp]
2023-01-31 Removed extra debug print
2023-02-06 Added wiring diagram
2023-02-06 Added Wiring Diagram to README
2023-02-06 Added Wiring Diagram Notes to README
2023-02-06 increased default low battery sleep interval
2023-02-06 Added information about low battery error screen
2023-02-06 added function to return the meaning of wifi errors
    [display_utils.cpp]
2023-02-06 Added improved wifi error messages
    [main.cpp]
2023-02-07 Updated wifi error messages
    [main.cpp]
2023-02-11 Improved error handling for json deserialization
    [api_response.h, client_utils.cpp, display_utils.cpp]
2023-02-11 corrected maximum_ram_size for firebeetle esp32-e #11
2023-02-11 removed extra debug prints
2023-02-14 Added additional compensation for clock error
    [main.cpp]
2023-02-16 fix for long 1ln alerts not showing
    [renderer.cpp]
2023-02-17 Created macro for switching between B/W and 3 color epaper
2023-03-03 added extra logic to prevent 1 extra after bedtime
    [main.cpp]
2023-03-10 correcting slight mistakes in low battery behaviour (#20)
2023-03-21 Fixed ambiguous overload error #22
    [main.cpp]
2023-03-22 created seperate env for firebeetle board varients
2023-04-03 corrected capitalization of locale names
    [config.h]
2023-04-08 fix for out of bounds array access #28
    [display_utils.cpp]
2023-04-10 changed wifi and biohazard icons, added error icon
    [display_utils.cpp, main.cpp, renderer.cpp]
2023-04-13 reverted default language to American English
    [config.h]
2023-05-27 removed trailing whitespace, fixed typos
    [api_response.h, client_utils.cpp, config.h]
2023-06-03 added missing explicit namespace qualifications, improved clarity of some function signatures
    [display_utils.cpp, main.cpp, renderer.cpp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]
2023-09-03 Added 3d printable frame
    [frame.stl, frame.stp, mount_plate.stl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]
2023-09-09 Feature/40 support waveshare75v1 (#41)
    * feat: add basic support for waveshare 7.5 v1
    * docs: add info for v1 support
    * feat: less icons + adaptions for smaller screen
    * fix: select display bw v2 as default
    * Update platformio/src/renderer.cpp
    * Update platformio/src/renderer.cpp
    * Update platformio/src/renderer.cpp
    ---------
    [config.h, renderer.cpp, renderer.h]
2023-09-10 Fix display paging, new debug option, documentation clarity improvements
    [client_utils.cpp, config.h, main.cpp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]
2023-10-20 Fixes to enable more reliable NTP synchronization.
    [client_utils.cpp, config.h]
2023-11-04 configuration file updates, added battery monitoring option
2023-11-18 Make it possible to show rain volume (#64)
    * Make it possible to show rain volume
    Makes it possible to switch between showing
    Posibility of Precipitation (PoP) and rain volume in mm
    * Make it possible to specify the unit for precipitation graph
    * added automatic Y-major-tick precision
    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
2023-11-19 fixed bug with wrong timespace for air pollution requests
    [config.h, main.cpp]
2023-11-19 added wiring diagram for despi
2023-12-15 moved models to external links
    [frame.stl, frame.stp, mount_plate.stl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]
2023-12-17 low power improvements, display and bme now powered off GPIO pins
2023-12-23 added correct handling for waveshare and despi-c02 driver boards
    [config.h, renderer.cpp]
2023-12-25 Update README.md (#70)
    Added a new Printables Model
2023-12-28 updated despi-c02 wiring diagram to indicate correct RESE setting
2024-01-12 corrected DISPLAY_ALERTS macro behavior
    [main.cpp]
2024-02-16 http and json deserialization error codes are now translatable
    [display_utils.cpp]
2024-02-17 battery voltage is now calculated using eFuse calibration #79
2024-02-17 use min 3000mv to calculate battery percentage
2024-02-28 updated in-line comment to be general to any driver board
2024-03-02 bumped dependency versions, removed use of deprecated arduinojson functions
2024-03-03 fixed usued variable warning when DEBUG_LEVEL=0
    [display_utils.cpp]
2024-03-04 Add link to new 3d printable base #83
2024-03-15 Add translation for Portuguese Brazil (#86)
    * Create locale_pt_BR.inc
    Add - Translation for Portuguese Brazil
    * Update config.h
    Update locales description
    * replaced unicode characters with ascii, added missing translation for http response 425
    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
    [config.h]
2024-04-13 Added link to new enclosure to README.md #93
2024-04-15 Fixed capitalization in comments
    [config.h]
2024-04-18 Translations to estonian (#94)
    * added estonian language
    * Corrected language-territory code (ee_EE -> et_EE)
    * Corrected language-territory code (ee_EE -> et_EE)
    * Update locale_et_EE.inc
    * updated estonian CAQI translations
    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
    [config.h]
2024-04-20 Added more warnings about waveshare driver board support
2024-04-22 fixes for fi_FI locale
    [config.h]
2024-04-29 updated api calls to check wifi connection on retry to provide more precise errors
    [client_utils.cpp, display_utils.cpp]
2024-05-04 Added http client tcp timeout option, fix for #83
    [client_utils.cpp, config.h]
2024-05-09 updated cert chain script, removed use of deprecated feature
2024-08-25 safer and more practical battery low power cutoff values #121
2024-08-25 always do spi remapping #101
2024-08-25 add space between quantity and unit for precipitation graph y-axis
2024-09-06 updated certificate chain for api.openweathermap.org:443
2024-10-27 fixed bug that would cause sleep durations to sometimes being twice as long as they should be
    [main.cpp]
2025-01-05 use default display init reset for despi #133
    [renderer.cpp]
2025-01-06 Display hourly icons above temperature line (#136)
    * Display hourly weather icons on temperature chart
    Generates pointers to 32 pc bitmaps which are then drawn at the x-axis tick marks except for the first and last one and the above the temperature line.
    Tested with different HOURLY_GRAPH_MAX.
    Still readable if precipitation overlaps, however a grayscale option would be truly amazing for this (is this feasible?).
    Currently does not differentiate between moon present or absent, night time is always with moon.
    Only tested with DISP_BW_V2, therefore only enabled for this display.
    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
2025-01-24 Added link to new community 3d printable stand #152
2025-01-26 Updating README to include how to manually put ESP32-E in "download mode" (#153)
2025-03-12 Fix -1: Connection Refused, updated certificate #165
    [config.h, main.cpp]
2025-03-22 Restructured readme for clarity. Updated wiring diagram
2025-03-24 add support for BME680 sensor (#169)
    * add support for BME680 sensor
    * minor formatting
    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
2025-03-24 Add a decimal place to the indoor temperature value (#170)
    * Add a decimal place to the indoor temperature value
    * use std::round to avoid bug with using String to round, don't round fahrenheit
    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
    [renderer.cpp]
2025-11-17 Add config flags to display or not battery level and WiFi signal strenth texts (#201)
2026-01-05 Add a config interchange High | Low (#204)
    * Add temperature order configuration options
    Added configuration options for temperature order.
    * Adjust temperature string drawing order based on flags
2026-01-05 Make left panel a lot more customizable (#208)
    * Update locale header with new weather constants
    Added new constants for moon phases and current conditions.
    * Add customizable icon order
    Added configuration options for customizing icon order
    * Add moon phase utility functions to display_utils.h
    * Add new functions for weather data rendering
    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
2026-01-05 Added link to new 3d printable stand #206
2026-01-05 Added link to new 3d printable stand #190
2026-01-08 Add dew point display (#212)
    * add dew point
    * Add function to draw current dew point on display
    * Add function to draw current dewpoint
    * Comment out POS_DEWPOINT definition in config.h
    * Update locale header with additional constants
    * Add files via upload
    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
2026-01-08 BME sensor delay (#211)
2026-03-23 updated driver display definitions (#160)

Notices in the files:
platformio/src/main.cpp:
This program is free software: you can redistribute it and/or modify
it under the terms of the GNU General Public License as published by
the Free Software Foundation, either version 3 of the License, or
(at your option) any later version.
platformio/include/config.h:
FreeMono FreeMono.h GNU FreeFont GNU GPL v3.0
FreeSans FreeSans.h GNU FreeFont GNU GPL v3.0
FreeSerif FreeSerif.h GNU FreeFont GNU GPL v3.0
